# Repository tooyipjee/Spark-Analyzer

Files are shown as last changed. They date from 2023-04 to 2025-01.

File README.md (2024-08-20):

# Spark Analyzer: The Programmable USB-C Power Delivery Analyzer & Power Supply

<p align="center">
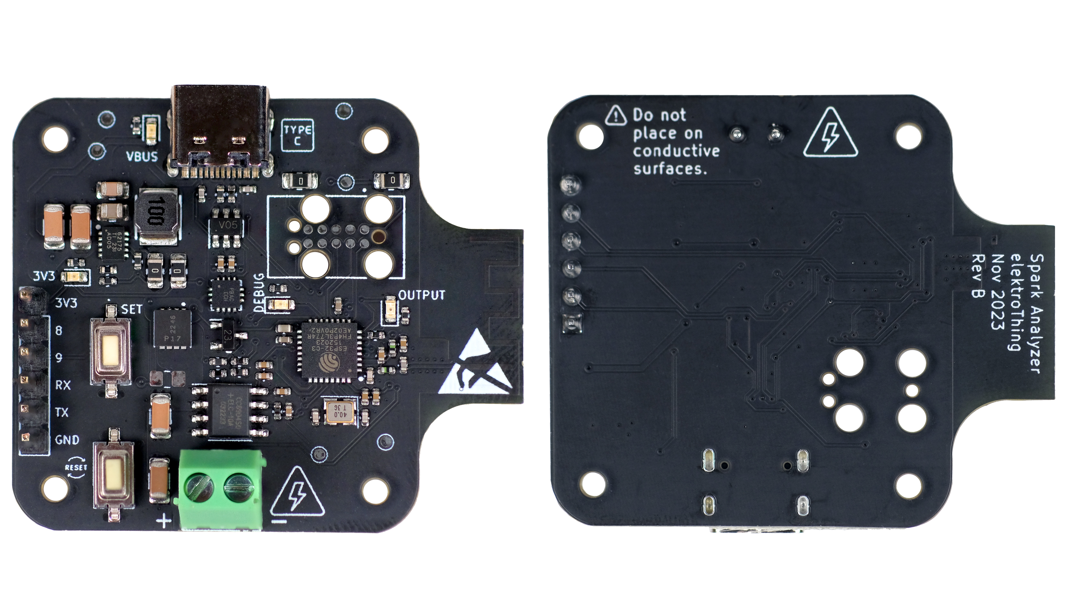
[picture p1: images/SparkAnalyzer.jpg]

</p>

**Just received your Spark Analyzer? Check out our [quickstart guide](https://www.elektrothing.com/spark-analyzer-quickstart)!**

The **Spark Analyzer** excels in power management. It is a versatile ESP32-powered device tailored for enhancing project development and debugging processes. It is fully compatible with USB-C Power Delivery (PD) and also supports the Programmable Power Supply (PPS) feature, allowing for precise control and management of power. Its compact design facilitates easy inline integration with existing setups, providing essential insights and control over power delivery.

Equipped with WiFi and BLE, the Spark Analyzer offers wireless connectivity, enabling developers to remotely monitor and adjust voltage levels, log data, and analyze power consumption through a user-friendly interface. This design prioritizes convenience and efficiency, removing the need for physical buttons and supporting distance operation.

Fully funded on Crowdsupply [now](https://www.crowdsupply.com/elektrothing/spark-analyzer).

Spark Analyzer (https://www.youtube.com/watch?v=IWUR4Ur0Dy4)

## Features:

1. **Configure USB Power Delivery PD**: When the Spark Analyzer is connected to a USB port that supports Power Delivery (PD), you can configure the output voltage as 5V, 9V, 15V or 20V.

2. **Configure USB Programmable Power Supply PPS**: When the Spark Analyzer is connected to a USB port that supports Programmable Power Supply (PPS), then you can configure the output voltage between 3.3V and 21V in steps of 20 mV. You can also limit the current up to 3A in steps of 50mA.

3. **Power Analysis**: The Spark Analyzer comes with a current sensor. This allows for accurate current draw measurements, essential for understanding power usage in your projects.

4. **Wireless Control**: Untehther your development process with the Spark Analyzer’s wireless capabilities. With both WiFi and BLE, this tool allows remote control and data logging. Users can adjust settings and monitor data from a distance, offering a more flexible development experience.

5. **Open Source & Programmable**: As an open-source device, the Spark Analyzer offers unmatched versatility. It is fully programmable, allowing you to tailor its functionality to your specific applications. This customization extends to software and hardware, opening up endless possibilities for creative and efficient project development.

6. **Compact Design**: Designed for convenience, the Spark Analyzer's compact and sleek form factor allows for seamless integration into existing setups. Its compatibility with USB PD power sources and inline integration capability minimizes the need for additional equipment or extensive redesign, making it a versatile and user-friendly addition to any development environment.

5. **Safety**: Safety is crucial when working with electricity and is at the heart of Spark Analyzer. An integrated output FET allows for software programmable current limit that switches off the power in high-current scenarios.

## Specifications

#### Power
- **Negotiable Power Delivery**: Options of 5 VDC, 9 VDC, 12 VDC, 15 VDC, 20 VDC; max 5 A (100 W at 20 VDC). It is also PPS compatible up to 21 VDC. Note: the Spark Analyzer comes preinstalled with firmware that supports PD. If you want to use PPS you can load this version instead: [WebApp_PPS](https://github.com/tooyipjee/Spark-Analyzer/tree/master/PlatformIO/WebApp_PPS).
- **USB Type-C Port**: For power delivery and integrated JTAG programming.
- **ON Semiconductor [FUSB302MPX](https://www.onsemi.com/pdf/datasheet/fusb302b-d.pdf)**: Programmable USB Type-C control and USB PD communication.
- **ESD Protection**: On D+/D-/CC1/CC2 pins.
- **Texas Instruments [TPS62175DQCT](https://www.ti.com/product/TPS62175/part-details/TPS62175DQCT)**: 3.3 VDC 0.5 A max output DC-DC Step-Down Converter.
- **Power Output**: 3.5 mm, 2-position terminal block.

#### I/O Configuration
- **GPIOs**: 4 GPIOs (I2C, UART, SPI compatible).
- **Power Pins**: 1x 5 VDC and 1x GND.

#### Microcontroller
- **Model**: [ESP32-C3FH4](https://www.espressif.com/sites/default/files/documentation/esp32-c3_datasheet_en.pdf) with 40 MHz crystal.
- **Wi-Fi**: 802.11b/g/n.
- **Bluetooth**: BLE 4.2.
- **Flash Memory**: 4 MB.

#### Interface
- **3x LED Indicators**
  - Power On
  - Output Enable
  - Programmable LED/Debug
- **Buttons**
  - Reset
  - Programmable Button/Debug

#### Programming
- **Integrated JTAG Controller**: For programming.
- **USB-C**: Built-in USB JTAG programmer (ESP32-C3), compatible with Arduino. Select ESP32-C3 Dev Board.

#### Output
- **Current Output**: [CC6904SO-10A](https://datasheet.lcsc.com/lcsc/2304140030_Cross-chip-CC6904SO-10A_C469389.pdf).
- **Current Sensor**: Hall Effect Current Sensor.
- **Output Enable**: [DMP3017SFG-7 FET](https://www.diodes.com/assets/Datasheets/products_inactive_data/DMP3017SFG.pdf).

<p align="center">
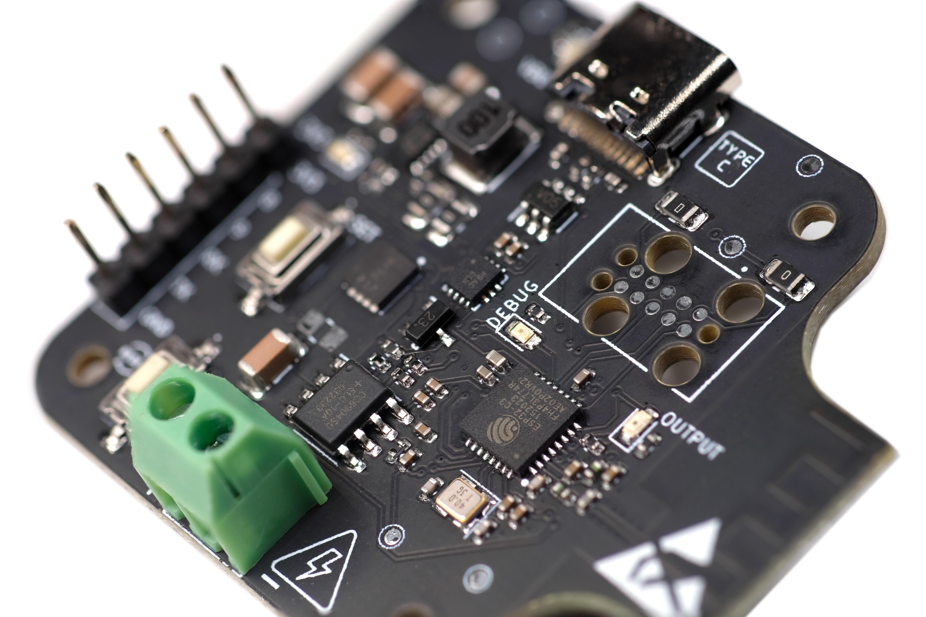
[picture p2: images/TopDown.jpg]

</p>

## Spark Analyzer Mobile App

<p align="center">
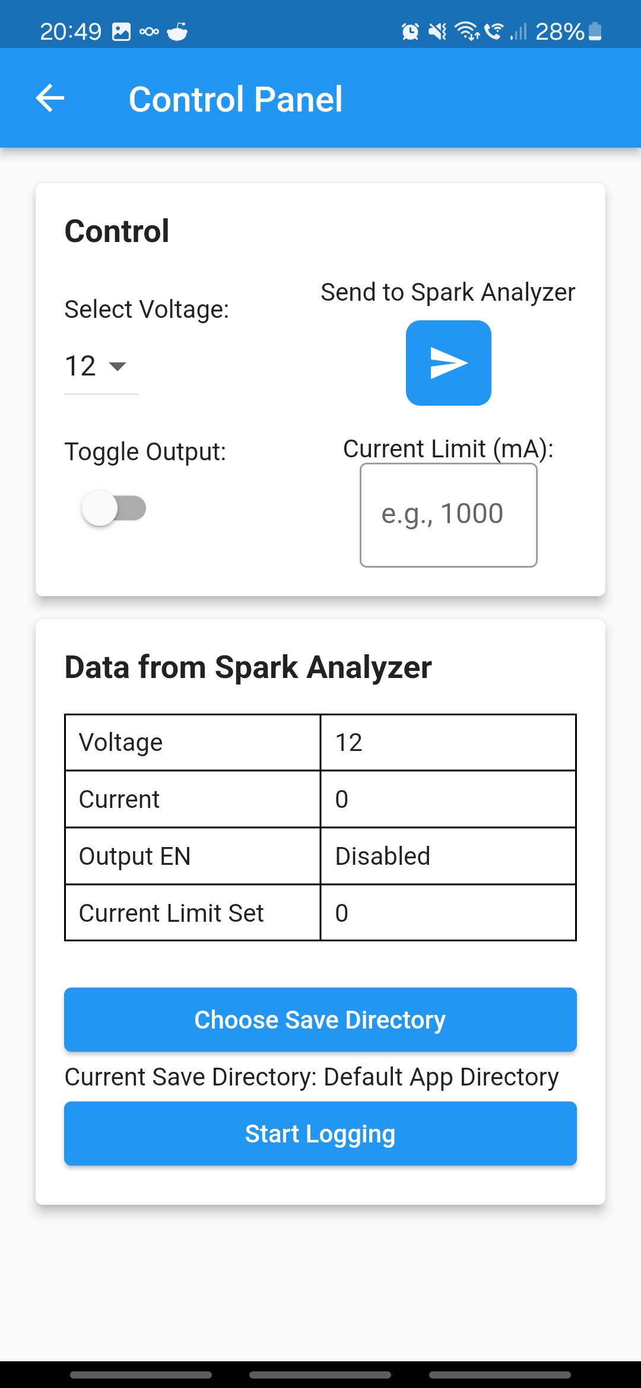
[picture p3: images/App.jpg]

</p>

> **Note**: The Spark Analyzer Mobile App is currently in active development. The features described below are subject to change as we continue to improve the app.

The Spark Analyzer Mobile App, currently done for [Android](https://play.google.com/store/apps/details?id=com.elektrothing.SparkAnalyzer&hl=en&gl=US) (iOS support is available via [RemoteXY](https://apps.apple.com/us/app/remotexy/id1168130280), is the perfect companion to your Spark Analyzer device. It simplifies monitoring and controlling power delivery with these key features:

- **Voltage Selector**: Easily choose from different voltage levels (5 VDC, 9 VDC, 15 VDC, or 20 VDC) using a user-friendly selector.
- **Output Toggle**: Turn the power output on or off conveniently with a toggle switch.
- **Current Logging**: Save current draw as a .csv file.
- **Current Limit**: Ability to set a software current trip as a safety feature.
- **Read-time Display**: View current set point, current draw and output enable in real time on your phone.

### Key Features:

- **Voltage Selector**: The app comes with a user-friendly voltage selector that allows you to easily choose from the different voltage levels supported by the UCPD protocol. Whether you need 5V, 9V, 15V, or 20V, switching between these options is just a tap away.

- **Output Toggle**: Need to turn the power output on or off? The app features a convenient toggle switch that gives you full control over the Spark Analyzer's output, making it simple to manage your device remotely.

- **Current Draw Chart**: Keep an eye on your project's power consumption with the app's real-time current draw chart. This feature provides a graphical representation of the current being drawn, helping you to monitor and optimize your power usage effectively.

### Future Developments:

The Spark Analyzer Mobile App is continuously being improved, with several new features in the pipeline. Upcoming updates will include the ability to export logs for further analysis, set current limits to prevent overcurrent scenarios, and much more.

## Testing for Performance

At the heart of Spark Analyzer's design is a commitment to reliability and performance. To ensure that Spark Analyzer stands up to real-world demands, we subjected it to testing under use conditions.

### Max Current Test: 3A at 9V
Under a load condition of 3A at 9V, Spark Analyzer showcased its robust power delivery capabilities without any hitches.

<p align="center">
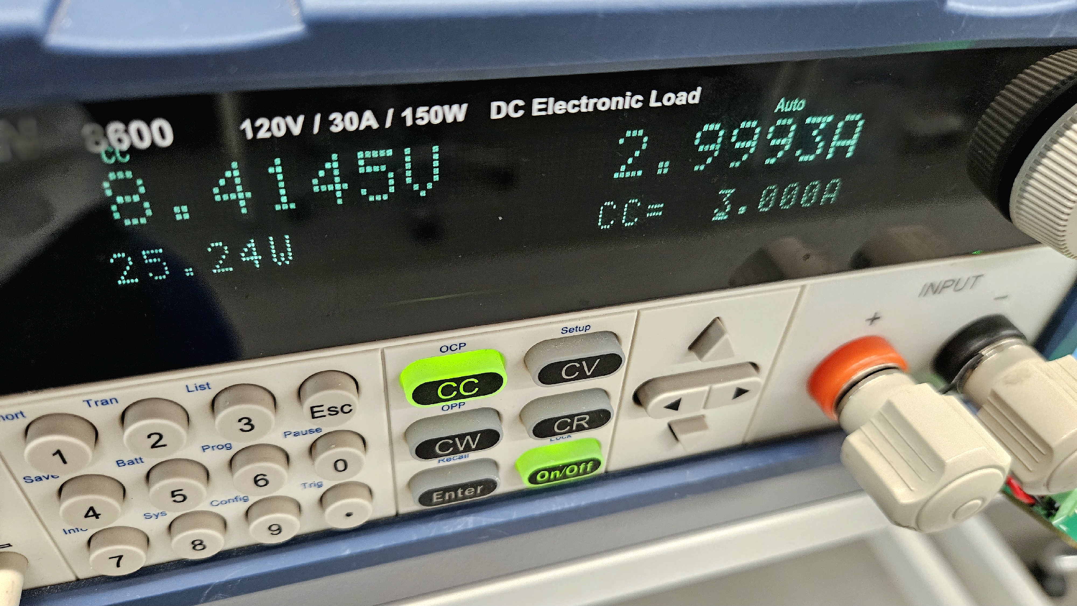
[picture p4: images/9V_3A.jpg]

</p>

### Max Voltage Test: 1.5A at 20V
Even at its maximum voltage output of 20V with a 1.5A load, Spark Analyzer continued to perform seamlessly, demonstrating its versatility and reliability.

<p align="center">
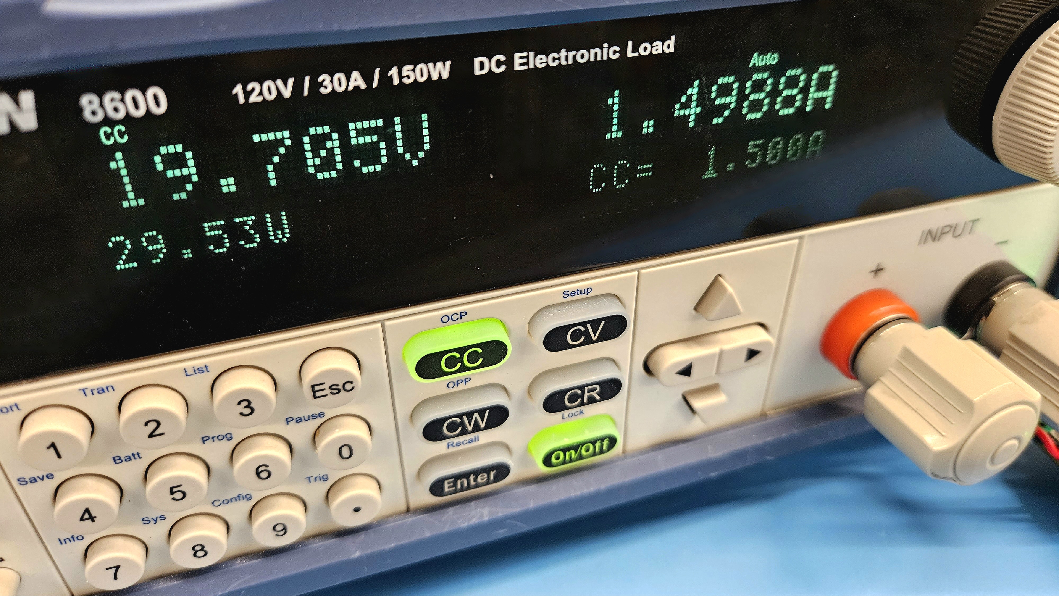
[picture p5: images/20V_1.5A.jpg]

</p>

### Thermal Performance
Safety and efficiency are paramount. We took a thermal image of the board under these testing conditions to ensure that all components remained within safe temperature limits. The results were impressive: the entire board stayed cool, with the warmest component being the ESP32 microcontroller, which only reached around 40°C.

<p align="center">
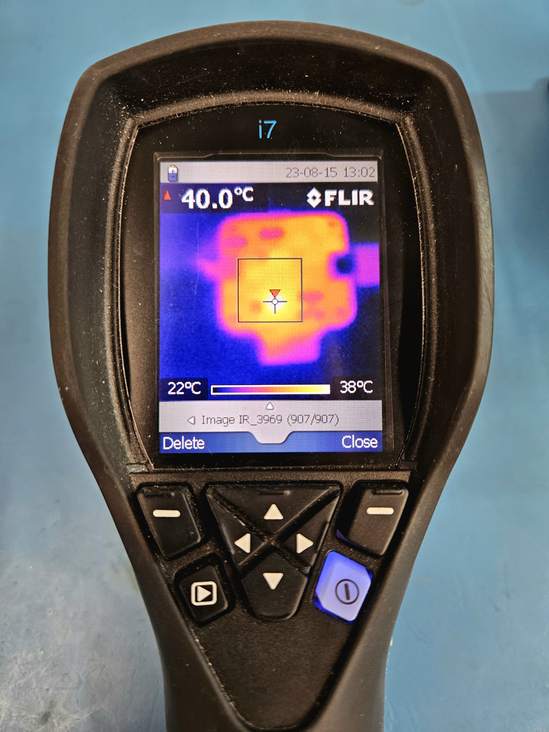
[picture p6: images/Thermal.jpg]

</p>

These tests underscore Spark Analyzer's commitment to delivering a product that is not only feature-rich but also reliable, safe, and efficient. With Spark Analyzer, you're investing in a device that's been tried and tested to ensure optimal performance under all conditions.

## Package Contents:

- 1x Spark Analyzer
- Additional components (Specify as per your package)

## Manufacturing & Logistics:

Our designs have undergone rigorous testing and verification. We've already produced a pilot batch, and our manufacturing partners are geared up for full-scale production. All Spark Analyzer units will be shipped globally, ensuring timely delivery to our backers.

## Comparison: Spark Analyzer vs PD Micro vs Lab Power Supply

| | Spark Analyzer | [PD Micro](https://www.mouser.co.uk/ProductDetail/Crowd-Supply/CS-PDMICRO-01?qs=TuK3vfAjtkXixx0TeJooNQ%3D%3D) | [TinyPICO V3](https://www.conrad.com/en/p/joy-it-com-zy12pdn-converter-1-pc-s-2475888.html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) | [Joy-IT COM ZY12PDN](https://shop.pimoroni.com/products/tinypico-v2?variant=39285089534035) |
|---|---|---|---|---|
| **Microcontroller** | ESP32-C3 | ATmega32U4 | ESP32-PICO-D4 | Not Applicable |
| **WiFi Connectivity** | Available (802.11b/g/n) | Not Available | Available | Not Available |
| **Bluetooth Connectivity** | Available (BLE 4.2) | Not Available | Available | Not Available |
| **Flash Memory** | 4 MB | Not Specified | 4 MB | Not Specified |
| **USB-C Power Delivery** | Supported | Supported | Not Supported | Supported |
| **Output Control** | Adjustable | Adjustable | Not Specified | Adjustable |
| **Wireless Control** | Yes | No | Yes | No |
| **Smartphone App Support** | Yes | No | No | No |
| **Power Analysis** | Accurate | Basic | Not Specified | Basic |
| **Design** | Compact and Sleek | Compact | Ultra-Small | Compact |
| **Open Source Status** | Yes | Yes | Yes | No |
| **Programming Interface** | USB + JTAG | USB | USB | Not Applicable |
| **Inline Integration** | Yes | No | Not Applicable | No |
| Power Delivery Range | 5-20 VDC Supported | 5-20 VDC Supported | Not Supported | 5-20 VDC Supported |
| **Price (USD)** | $49 | $28 | $22 | $16 |

## License

MIT License

Copyright (c) 2023 elektroThing

Permission is hereby granted, free of charge, to any person obtaining a copy
of this software and associated documentation files (the "Software"), to deal
in the Software without restriction, including without limitation the rights
to use, copy, modify, merge, publish, distribute, sublicense, and/or sell
copies of the Software, and to permit persons to whom the Software is
furnished to do so, subject to the following conditions:

The above copyright notice and this permission notice shall be included in all
copies or substantial portions of the Software.

THE SOFTWARE IS PROVIDED "AS IS", WITHOUT WARRANTY OF ANY KIND, EXPRESS OR
IMPLIED, INCLUDING BUT NOT LIMITED TO THE WARRANTIES OF MERCHANTABILITY,
FITNESS FOR A PARTICULAR PURPOSE AND NONINFRINGEMENT. IN NO EVENT SHALL THE
AUTHORS OR COPYRIGHT HOLDERS BE LIABLE FOR ANY CLAIM, DAMAGES OR OTHER
LIABILITY, WHETHER IN AN ACTION OF CONTRACT, TORT OR OTHERWISE, ARISING FROM,
OUT OF OR IN CONNECTION WITH THE SOFTWARE OR THE USE OR OTHER DEALINGS IN THE
SOFTWARE.

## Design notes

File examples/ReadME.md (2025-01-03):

# Spark Analyzer Quickstart Guide

Thank you for your purchase! Let's get started.

Your Spark Analyzer ships with the Web App PD firmware. Follow this guide to begin. For more detailed information, refer to the datasheet in the [project repository](link-to-repository).

## Hardware Setup

1. **Connect to a USB-C PD Compatible Wall Wart:** Ensure your wall adapter supports USB-C PD by looking for "USB PD" markings or output specifications above 5V (e.g., 9V, 15V, 20V).  USB-C alone doesn't guarantee PD compatibility. [See an example](link-to-example-image).

2. **Power On:** Turn on your Spark Analyzer. A blinking debug LED (5 times) confirms the firmware is loaded correctly.

## WiFi Connection

1. **Connect to "Spark Analyzer" WiFi:**  Using a WiFi-enabled device (phone or laptop), connect to the "Spark Analyzer" network.  Internet access isn't required for this step.

2. **Configure WiFi:** Open a web browser and navigate to `192.168.4.1` to access WiFiManager. Enter your home or office WiFi credentials.

## Accessing the Web App

### Find Device IP

* **Serial Monitor:** Connect the device to your computer via USB. The IP address will display in your IDE's serial monitor once connected to WiFi.

* **BLE Advertisement:**  Use a BLE scanner app (like NRF Connect) to locate the device broadcasting its IP address.

### Web App Interface

1. **Launch Web App:** Enter the device's IP address into your web browser.

### Web Interface Overview

* **Current Graph:**  Displays real-time current measurements.
* **Select and Set Voltage:** Choose and apply the desired voltage.
* **Output Control:**  Turn the device's power output on or off.

That's it! You're ready to control your Spark Analyzer's USB-C PD functions. For more examples and applications, explore the [project repository](link-to-repository).

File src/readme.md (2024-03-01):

# Spark Analyzer Firmware Collection

Welcome to the Spark Analyzer Firmware Collection! This repository is a comprehensive suite of firmware scripts specifically designed for the Spark Analyzer, a versatile tool for power management and smart device control. The firmware collection showcases a range of functionalities, from wireless communication and smart home integration to precise power delivery and current monitoring. Each script is crafted to demonstrate and utilize the unique features of the Spark Analyzer, making them ideal for a variety of applications in IoT, smart home, and power management sectors. Below is an overview of the available firmware scripts:

Most of them are Arduino examples and there is one template PlatformIO firmware that you can use to build your projects. Here are the main scripts/examples;
## 1. [Spark Analyzer Firmware with BLE and USB-C PD Control](https://github.com/tooyipjee/Spark-Analyzer/tree/master/src/Arduino/flutter_controller)
- **Purpose**: Focuses on Bluetooth Low Energy (BLE) communication for remote control and monitoring. [Google Play](https://play.google.com/store/apps/details?id=com.elektrothing.SparkAnalyzer&hl=en&gl=US)
- **Key Features**:
  - Manages USB-C Power Delivery (PD) for voltage control.
  - Implements a moving average filter for stable current readings.
  - Utilizes EEPROM for storing voltage settings.
  - LED indicators for operational status.

## 2. [Spark Analyzer Firmware for ESP-NOW Communication](https://github.com/tooyipjee/Spark-Analyzer/tree/master/src/Arduino/esp-now)
- **Purpose**: Provides host and peripheral setup for ESP-NOW communication.
- **Host Script**:
  - Sends voltage and enable/disable commands to peripherals.
- **Peripheral Script**:
  - Receives commands to control a NeoPixel LED strip and manage USB-C PD.
  - Processes structured data from the host.

## 3. [Spark Analyzer Firmware for Matter Integration](https://github.com/tooyipjee/Spark-Analyzer/tree/master/src/Arduino/matter_controller)
- **Purpose**: Integrates with Matter (formerly Project CHIP) for smart home connectivity.
- **Key Features**:
  - Control of an LED via Matter's OnOff cluster.
  - USB-C PD integration for voltage management.
  - Toggle button implementation with debouncing.
  - Serial communication for device status and debugging.

## 4. [Spark Analyzer Template Firmware for Custom Applications](https://github.com/tooyipjee/Spark-Analyzer/tree/master/src/Arduino/template)
- **Purpose**: Serves as a base for developers creating custom applications.
- **Key Features**:
  - Includes USB-C PD management for voltage setting.
  - Real-time ADC reading with a moving average filter.
  - Configurable initial output state and current limit.
  - Serial communication for debugging and status updates.

## 5. [PlatformIO Template Firmware for USB-C PD and Current Monitoring](https://github.com/tooyipjee/Spark-Analyzer/tree/master/src/PlatformIO/SparkAnalyzer)
- **Purpose**: Optimized for use in PlatformIO environment.
- **Key Features**:
  - USB-C PD initialization and management.
  - Real-time current measurement with a moving average filter.
  - Function prototypes for better code organization.
  - Configurable update interval for monitoring.

Each firmware script in this collection highlights different capabilities of the Spark Analyzer, catering to a wide range of applications in power management, smart home systems, and IoT devices.

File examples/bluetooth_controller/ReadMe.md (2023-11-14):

### Spark Analyzer Code Guide

#### Overview
The Spark Analyzer code is designed for a Bluetooth Low Energy (BLE) connected power supply controller. It allows remote monitoring and control of a power supply's voltage and current draw via the RemoteXY app. The code includes functionality for adjusting voltage, turning the power supply on and off, and monitoring current consumption.

#### How the Code Works

1. **Initialization**: Sets up BLE connectivity, preferences, and initializes the USB-C Power Delivery (PD) with pre-stored voltage settings.

2. **Remote Control Interface**: Implemented using the RemoteXY service, which provides a graphical user interface (GUI) on a smartphone for remote interaction.

3. **Voltage Control**: Allows the selection of output voltages (5V, 9V, 12V, 15V, 20V) via a selector on the RemoteXY app interface.

4. **On/Off Control**: Includes an on/off switch on the RemoteXY app to enable or disable the power output.

5. **Current Monitoring**: Measures and displays the current draw in milliamperes (mA) on the app.

6. **ADC Filtering**: Uses a moving average filter to smooth out the analog-to-digital converter (ADC) readings for accurate current measurements.

7. **Preferences Management**: Saves and retrieves user settings (like set voltage) using the ESP32's Preferences library.

#### How to Use with RemoteXY App

##### Installing RemoteXY App
1. **Android Devices**:
   - Open the Google Play Store.
   - Search for "RemoteXY: Arduino control".
   - Install the app.

2. **iOS Devices**:
   - Open the Apple App Store.
   - Search for "RemoteXY: Arduino control".
   - Download and install the app.

##### Connecting to Spark Analyzer
1. **Open the RemoteXY App** on your smartphone.

2. **Connect to the Device**:
   - In the app, select the connection mode (BLE).
   - Scan for available devices and select "Spark Analyzer".

3. **Interface Overview**:
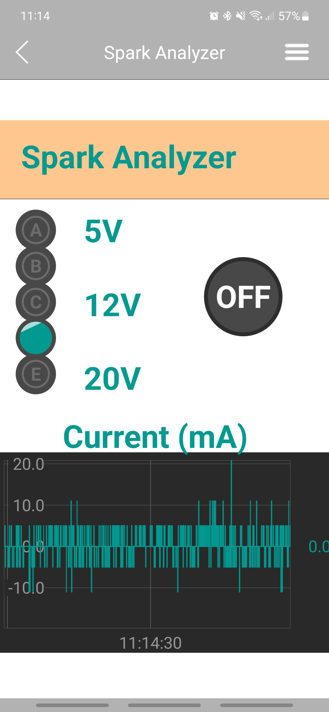
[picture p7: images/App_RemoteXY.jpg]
App Interface RemoteXY App Interface


   - **Voltage Selector (A to E)**: Select between 5V, 9V, 12V, 15V, and 20V. Labels indicate the corresponding voltages (5V, 12V, and 20V).
   - **On/Off Button**: A toggle switch to turn the power output on or off.
   - **Current Draw Chart**: Displays real-time current consumption in mA.

4. **Using the Interface**:
   - **Selecting Voltage**: Tap on the voltage selector (A to E) to choose the desired output voltage. Only select among the labeled voltages (5V, 12V, and 20V) for safety.
   - **Toggling Power**: Press the on/off button to enable or disable the power output.
   - **Monitoring Current**: View the current draw chart to see the live current consumption in milliamperes.

5. **Data Synchronization**: The app will continuously synchronize data with the Spark Analyzer, providing real-time updates on voltage and current readings.

#### Safety and Precautions
- Ensure that your power supply and hardware are compatible with the selected voltages and current levels.
- Use the app within the BLE range for stable communication.
- Regularly check connections and components for safety.

This guide assumes familiarity with basic electronic and BLE concepts. For specific hardware setup or advanced configurations, refer to the device's manual or technical documentation.

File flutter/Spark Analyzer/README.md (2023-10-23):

# ble_scan_demo

A new Flutter project.

## Getting Started

This project is a starting point for a Flutter application.

A few resources to get you started if this is your first Flutter project:

- [Lab: Write your first Flutter app](https://docs.flutter.dev/get-started/codelab)
- [Cookbook: Useful Flutter samples](https://docs.flutter.dev/cookbook)

For help getting started with Flutter development, view the
[online documentation](https://docs.flutter.dev/), which offers tutorials,
samples, guidance on mobile development, and a full API reference.

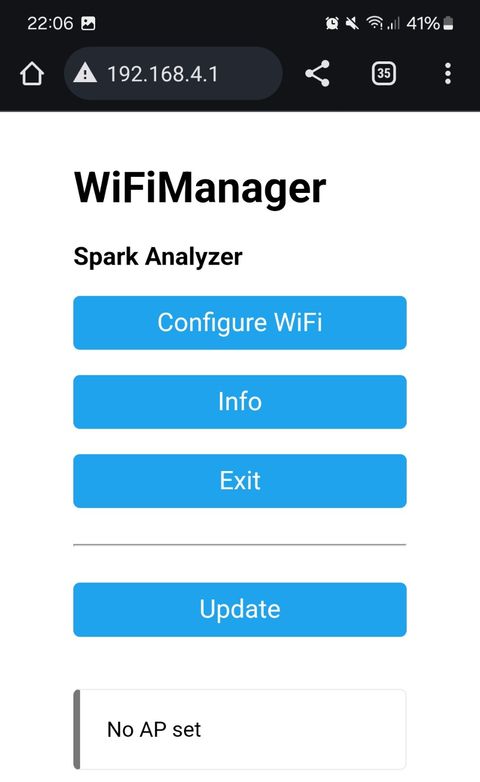
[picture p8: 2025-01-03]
images/quickstart/wifi_manager.jpeg

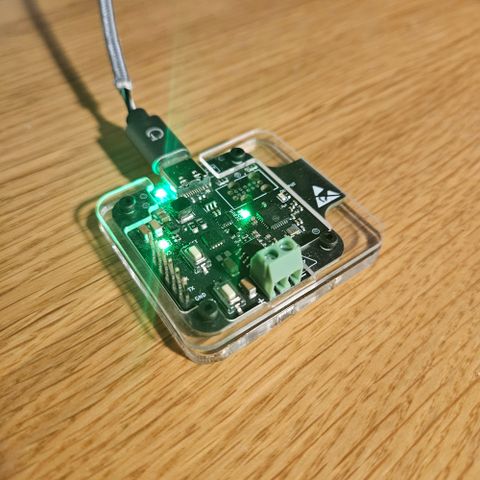
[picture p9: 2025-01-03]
images/quickstart/spark_analyzer_plugged.jpeg

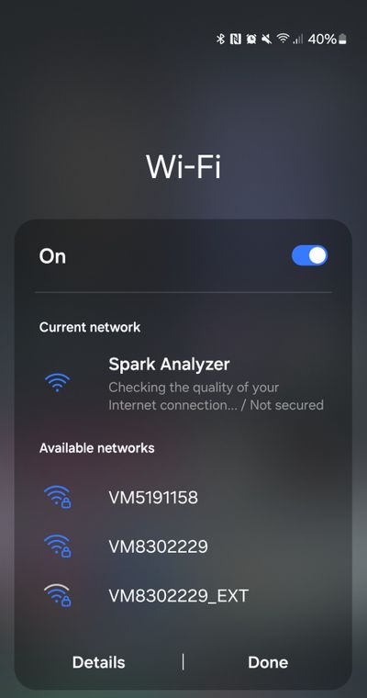
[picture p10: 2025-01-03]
images/quickstart/android_wifi.jpeg

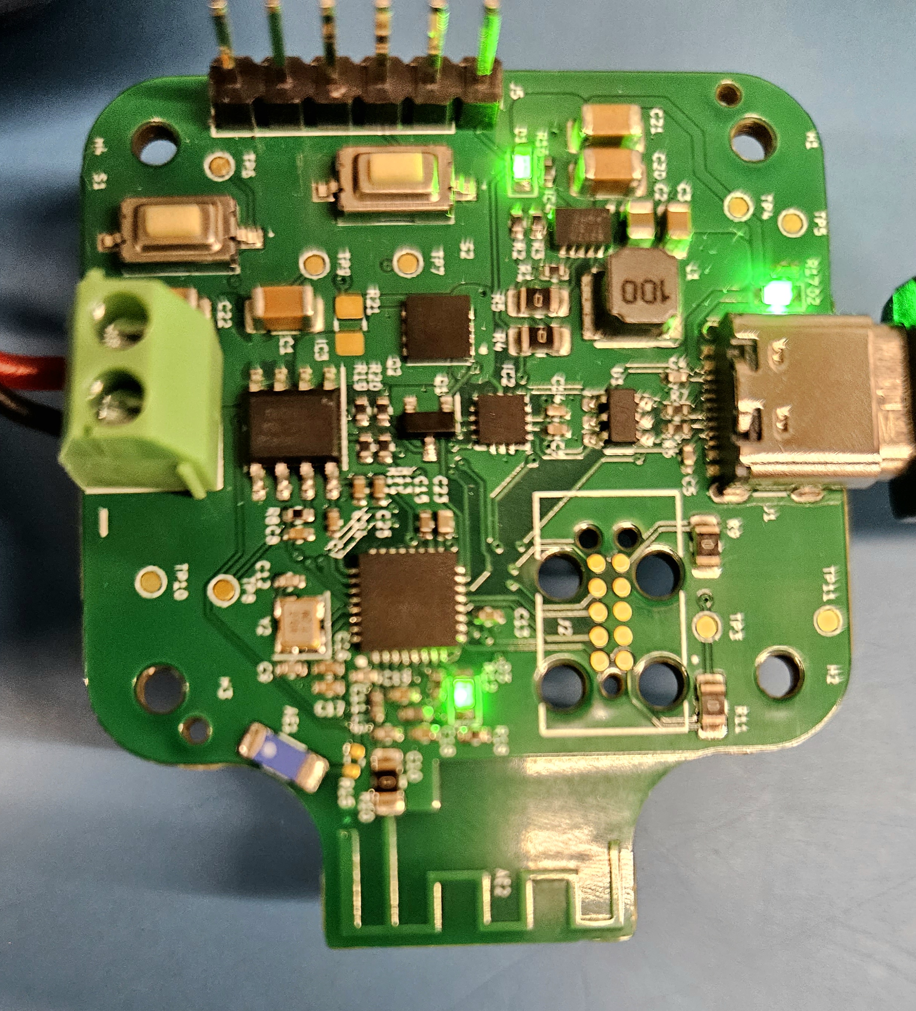
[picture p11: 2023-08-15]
images/ThermalColour.jpg

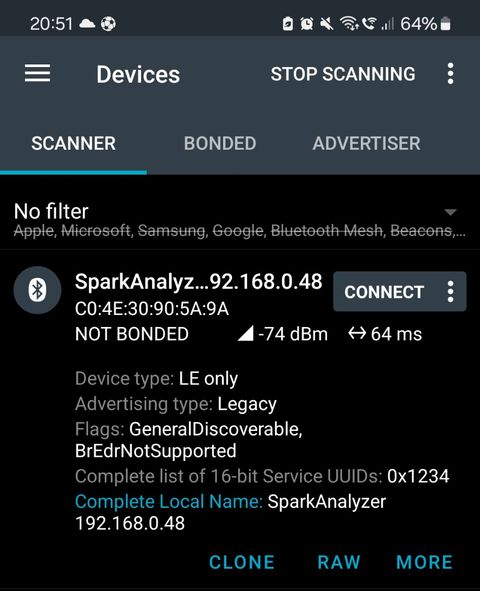
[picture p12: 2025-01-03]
images/quickstart/nrf_connect.jpeg

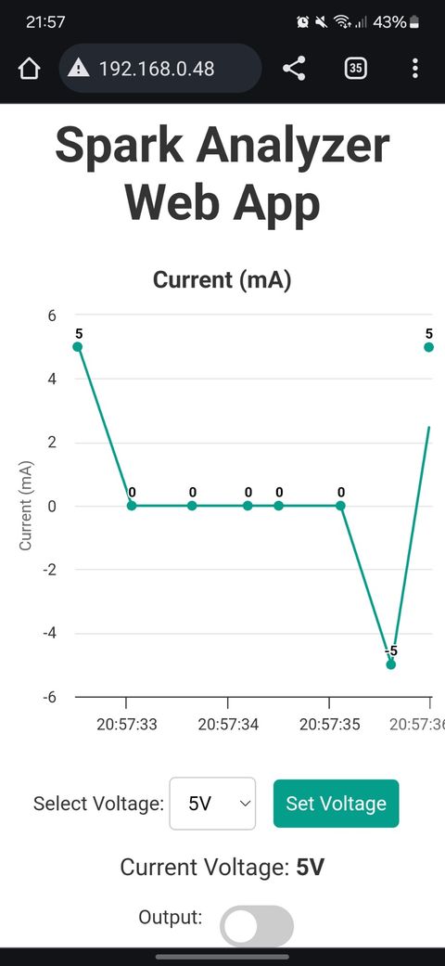
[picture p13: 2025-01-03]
images/quickstart/spark_analyzer_webapp.jpeg

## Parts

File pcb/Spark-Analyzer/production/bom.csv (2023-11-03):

Designator | Footprint | Quantity | Value | LCSC Part #
AE2 | Texas_SWRA117D_2.4GHz_Left | 1 | Antenna
C1, C20, C21, C22 | 1206 | 4 | 10u_1206 | C466808
C10 | 0402 | 1 | 4p | C311704
C11 | 0402 | 1 | 5p | C1573
C12, C9 | 0402 | 2 | 20p | C1554
C13, C15 | 0402 | 2 | 1u | C52923
C14, C16, C17, C18, C19, C24, C25, C6, C7, C8 | 0402 | 10 | 100n | C307331
C2 | 0805 | 1 | 22u | C602037
C23 | 0402 | 1 | 10u_0402 | C315248
C3 | 0805 | 1 | 10u | C15850
C4, C5 | 0402 | 2 | 100p | C1546
D1, D2, D4 | 0603 | 3 | Green_0603 | C72043
D3 | 0603 | 1 | Yellow_0603 | C72038
H1, H2, H3, H4 | MountingHole_2.2mm_M2 | 4 | MountingHole
IC2 | WQFN-14-1EP_2.5x2.5mm_P0.5mm_EP1.45x1.45mm | 1 | FUSB302MPX | C442699
IC3 | SOP-8_3.9x4.9mm_P1.27mm | 1 | CC6904SO-10A | C469389
IC4 | SON50P200X300X80-11N | 1 | TPS62175DQCT | C32097
IC5 | QFN50P500X500X90-33N-D | 1 | ESP32-C3FH4 | C2858491
J1 | GT-USB-7010A | 1 | GT-USB-7010 | C963370
J2 | TC2050-IDC | 1 | TC2050-IDC
J3 | KF350352P | 1 | KF350-3.5-2P | C474892
J5 | PinHeader_1x06_P2.54mm_Vertical | 1 | Conn_01x06 | C492405
L1 | INDPM4040X300N | 1 | 10uH | C38117
L2, L3 | 0402 | 2 | 1.8nH
Q1 | SOT95P237X125-3N | 1 | DTC143ECA-TP
Q2 | DMP3007SFG7 | 1 | DMP3017SFG-7 | DMP3017SFG
R1 | 0402 | 1 | 100k | C25741
R11, R4, R5, R9 | 0805 | 4 | 0 | C17477
R12, R13, R14, R19 | 0402 | 4 | 10k | C25744
R16, R17, R18, R22 | 0402 | 4 | 2.7k | C25885
R2 | 0402 | 1 | 1M2 | C413030
R20 | 0402 | 1 | 1k | C11702
R21 | 0805 | 1 | DNF_0805
R3 | 0402 | 1 | 383k | C163468
R6, R7 | 0402 | 2 | 22 | C25092
R8 | 0402 | 1 | 100 | C25076
S1, S2 | TS1101CW | 2 | TS-1101-C-W | C318938
TP10, TP11, TP3, TP4, TP5, TP8 | TestPoint_Pad_D1.0mm | 6 | TestPoint
U1 | SOT-23-6 | 1 | SRV05-4
Y2 | Crystal_SMD_2520-4Pin_2.5x2.0mm | 1 | SX25Y040000BF1T-C | C271649

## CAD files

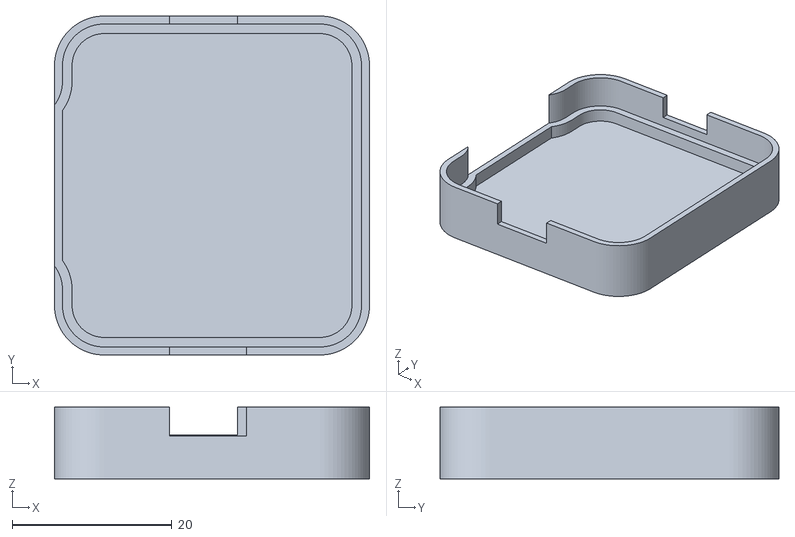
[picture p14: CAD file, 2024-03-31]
images/enclosure/Enclosure v3.stl
39.4 x 42.4 x 9.00

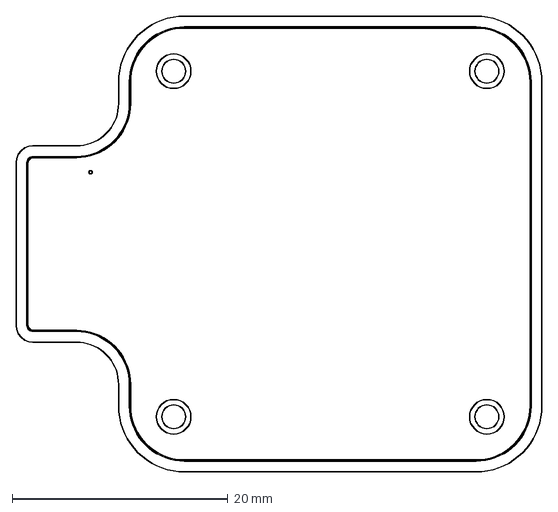
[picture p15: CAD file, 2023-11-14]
pcb/Spark-Analyzer/production/Board Outline with Margins.dxf
48.7 x 42.2 mm

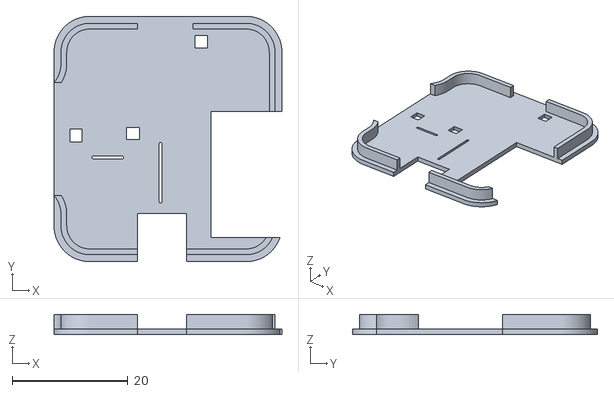
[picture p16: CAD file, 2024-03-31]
images/enclosure/Lid v1.stl
39.4 x 42.4 x 3.50

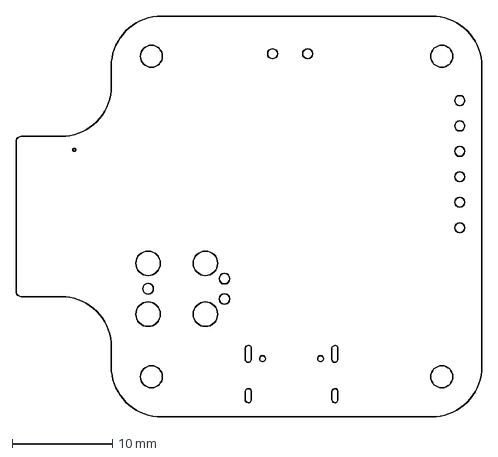
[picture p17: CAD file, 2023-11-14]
pcb/Spark-Analyzer/production/PCB_Outline.dxf
46.5 x 40.0 mm

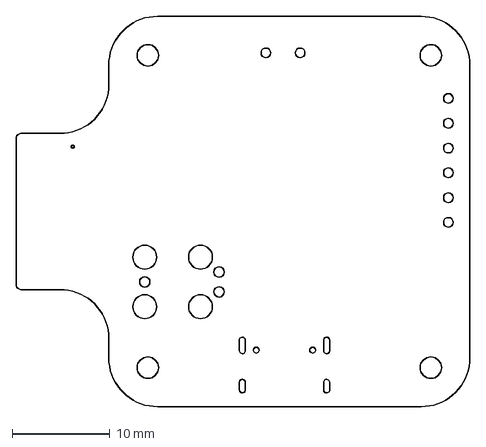
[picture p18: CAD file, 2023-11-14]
pcb/Spark-Analyzer/production/Board Outline.dxf
46.5 x 40.0 mm

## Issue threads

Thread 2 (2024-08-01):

How to configure 3.3V

doniks, 2024-08-01:
Just received my spark analyzer and plugged it in for the first time :heart:

I could
* connect to the spark analyzer access point
* configure my local wifi
* scan the ble advertisement to get the local IP
* open that IP in my browser
* turn it on
* measured it to be 5V
* also 9v works ok

so far so good, however,
* I don't see any way to configure voltages other than 5, 9, 12, 15, 20, like "Precisely control voltage from 3.3V to 21V at 20 mV resolution"
* I also don't see how to "set current limits up to 3A with 50mA resolution"

Is it somehow in ... I don't know "PD mode" and I have to switch it somehow to PPS?

tooyipjee, 2024-08-01:
The out of the box demo is a PD example.
PD doesn't support precise voltage control, you need to use PPS. You can
load this version instead;
Spark-Analyzer/PlatformIO/WebApp_PPS at master · tooyipjee/Spark-Analyzer
(github.com)
<https://github.com/tooyipjee/Spark-Analyzer/tree/master/PlatformIO/WebApp_PPS>

PPS supports 20mV and 50mA resolution, where it will trip the plug when you
draw too much.

Jason.

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

--
Sincerely,

*Jason Too*

doniks, 2024-08-01:
Thanks. Let me try that

doniks, 2024-08-01:
Mhm, so this was the first time using PlatformIO for me .. took me a while to figure out how to flash, but I can do it now, first with a blink example for `debug_led` and now I'm trying to flash back WebApp. It flashes and runs (according to some extra `Serial.println()` in `updateStatus()`, but I get

```
E (1442) SPIFFS: mount failed, -10025
[  1436][E][SPIFFS.cpp:89] begin(): Mounting SPIFFS failed! Error: -1
An Error has occurred while mounting SPIFFS
```

at boot, and no web interface.

could it be that maybe I wiped the SPIFFS with my blink example?! How could I make a kind of full flash, clean wipe ..

doniks, 2024-08-01:
ah, I had to [Use PlatformIO's "Upload Filesystem Image" command to upload the contents of the 'data' directory](https://github.com/tooyipjee/Spark-Analyzer/blob/master/PlatformIO/WebApp/src/main.cpp#L25)

doniks, 2024-08-01:
ok, so now I could reflash the WebApp version (including its filesystem) and that works again as expected.

I could also flash the WepApp_PPS version, including that corresponding FS. Now the website suggests that I can configure a granular voltage, and the serial terminal reflects that voltage, but if I measure the terminals with my voltmeter, I always see 5V

tooyipjee, 2024-08-01:
Please check that your USB-C plug supports PPS

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

doniks, 2024-08-01:
ahhhh :facepalm: I hadn't really grasped that before. So PPS is another feature/protocol that usb chargers might or might not support - got it.

Ok. seems my laptops usb-c ports do not support pps.

I have another charger which claims to support pps and lo and behold, I can configure it to 3.3 with that. Thanks! That clarifies my initial question. I could try and summarize it and make a PR to add it to the README!? Or other place if you prefer?

Having gotten that far now, I'd have a couple further feedback/remark
* It would be better if it would not fallback to 5v output if PPS is not supported. Rather keep the output off
* Maybe also show an error message in the web interface and maybe indicate via the led
* it seems that the web interface always comes up showing the output as on, even though it is (as expected) initially off
* even when I was unable to actually configure 3.3, because my charger was not PPS compatible the web app showed 3.3 . would it be possible to show 5 instead, or whatever would actually be put out
* it seems the PPS app does not remember the configured values. would it be sufficient to use the `Preferences` similar as in the WebApp? If so, I think I could make a PR for this
* oh, and just to not forget to state the obvious ... if at all possible, it would of course be much nicer if both PD and PPS could be supported in one firmware

tooyipjee, 2024-08-01:
Appreciate and feel free to make a PR yes! Haha thanks.

I need help from ppl like you!

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

doniks, 2024-08-03:
https://github.com/tooyipjee/Spark-Analyzer/pull/3

Closed 2024-08-04.

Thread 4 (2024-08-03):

WebApp_PPS should not deliver 5v if the power supply is not PPS capable

doniks, 2024-08-03:
previously discussed here: https://github.com/tooyipjee/Spark-Analyzer/issues/2

it seems that the WebApp_PPS falls back to delivering 5V if the power supply is not PPS capable. This could lead to people supplying higher voltage than what they want/anticipate.

I think the ideal solution would be to:
* detect that PPS is not supported
* show this in the web app
* turn off power output
* maybe the led can indicate some error state (does it support different colors? or rapid blinking)

tooyipjee, 2024-08-04:
Thanks for the feedback, I will try to get on this after the summer.

doniks, 2024-08-15:
when looking at the return value of `set_PPS()` :

```
bool retval = PD_UFP.set_PPS(PPS_V(ppsOutputVoltageV), PPS_A(ppsOutputCurrentLimitA));
      UART.printf("set_PPS(): %u\n", retval);
```
https://github.com/tooyipjee/Spark-Analyzer/pull/10/files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

I see a return value of
* `true` when I use a PPS capable adapter and then my voltmeter also shows the correct voltage configured
* `false` when I use a non-PPS adapter. And afterwards it delivers 5v.

So far that seems somewhat straight forward to detect success of failure. However, when I look at the actual library code, I find

> Set PPS Voltage in 20mV units, Current in 50mA units. return true if re-send request is needed
>   strict=true, If PPS setting is not qualified, return false, nothing is changed.
>   strict=false, if PPS setting is not qualified, fall back to regular power option

https://github.com/tooyipjee/Spark-Analyzer/blob/master/PlatformIO/WebApp_PPS/src/PD_UFP_Protocol.h#L145

which sounds less straight forward. in fact. I don't understand it

doniks, 2024-08-17:
added some more debugging here: https://github.com/tooyipjee/Spark-Analyzer/pull/11 `USE_PD_UFP_LOGGING`

which allows logging of detected power supply capabilities. I'm looking what I get from the various adapters I have lying around, but it's still confusing to me :( tbc

doniks, 2024-08-17:
maybe also better to [Examine the negotiated power value](https://github.com/ryan-ma/PD_Micro?tab=readme-ov-file#examine-the-negotiated-power-value) as per (upstream?) documentation and/or [Wait for USB PD PPS trigger completed](https://github.com/ryan-ma/PD_Micro?tab=readme-ov-file#wait-for-usb-pd-pps-trigger-completed)

doniks, 2024-08-18:
let me collect some logs and observations with the various chargers I have lying around

doniks, 2024-08-18:
# USB A
simplest case I guess, connecting to usb-A directly (specifically via a four port usb hub to the left port of my laptop)

1232: FUSB302 ver ID:A_revB
1273: 5.00V 1.00A supply ready
1273: USB attached CC2 vRd-USB

when pressing the reset button, it starts and then immediately restarts ...

ESP-ROM:esp32c3-api1-20210207
Build:Feb  7 2021
rst:0x1 (POWERON),boot:0x8 (SPI_FAST_FLASH_BOOT)
SPIWP:0xee
mode:DIO, clock div:1
load:0x3fcd5810,len:0x438
load:0x403cc710,len:0x90c
load:0x403ce710,len:0x2624
entry 0x403cc710
Initializing secondary serial port (GPIO pins)
Debug messages from Spark Analyzer code will be printed on this serial port
preferences.getType(V): 9
preferences.getType(A): 9
Mode: PPS
Voltage: 4.000 V
Current limit: 1.100 A
Connecting to wifi TP ..
Connected to wfif: TP (-72)
To access the web app, open your browser and navigate to -> http://192.168.1.244
[      1244] PPS mode, Voltage: 4.000 V, Current: 0 mA (1.100 A), Output: disabled
[      1276] PPS mode, Voltage: 4.000 V, Current: 0 mA (1.100 A), Output: disabled
Setup complete

1240: FUSB302 ver ID:A_revB
1282: 5.00V 1.00A supply ready
1282: USB attached CC2 vRd-USB
ESP-ROM:esp32c3-api1-20210207
Build:Feb  7 2021
rst:0x15 (USB_UART_CHIP_RESET),boot:0x8 (SPI_FAST_FLASH_BOOT)
Saved PC:0x42021efe
SPIWP:0xee
mode:DIO, clock div:1
load:0x3fcd5810,len:0x438
load:0x403cc710,len:0x90c
load:0x403ce710,len:0x2624
entry 0x403cc710
Initializing secondary serial port (GPIO pins)
Debug messages from Spark Analyzer code will be printed on this serial port
preferences.getType(V): 9
preferences.getType(A): 9
Mode: PPS
Voltage: 4.000 V
Current limit: 1.100 A
Connecting to wifi TP ..
Connected to wfif: TP (-72)
To access the web app, open your browser and navigate to -> http://192.168.1.244
[      1239] PPS mode, Voltage: 4.000 V, Current: 11 mA (1.100 A), Output: disabled
[      1271] PPS mode, Voltage: 4.000 V, Current: 11 mA (1.100 A), Output: disabled
Setup complete

1235: FUSB302 ver ID:A_revB
1277: 5.00V 1.00A supply ready
1277: USB attached CC2 vRd-USB
[     10000] PPS mode, Voltage: 4.000 V, Current: -5 mA (1.100 A), Output: disabled
[     20000] PPS mode, Voltage: 4.000 V, Current: 0 mA (1.100 A), Output: disabled

doniks, 2024-08-18:
# Ugreen adapter

this one seems to have some PPS capabilities. The charger has three usb c ports and one usb a port. the label is a bit scratched but as far as I can tell the different ports have different caps:

Power Delivery Fast Charger
Model: CD224

- USB-C1/C2 Output:
  - 5.0V@3.0A
  - 9.0V@3.0A
  - 12.0V@3.0A
  - 15.0V@3.0A
  - 20.0V@3.25A
  - 65W Max
- USB-C3 Output:
  - 5.0V@3.0A
  - 9.0V@3.0A ?? 2.0A ??
  - 12.0V@1.5A
  - 15??? W Max
- USB-A Output:
  - 4.5V@5.0A???
  - 5.0V@4.6A???
  - 5.0V@3.0A
  - ??V@2.0A
  - 12.0V@1.5??A
  - 22.5W Max

I think it's this one: https://nl.ugreen.com/collections/gan-oplader/products/ugreen-65w-usb-c-charger-4-poorts-oplader-pd-lader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 Can only find this in Dutch and it doesn't give specific details on the capabilities, but it has some complicated overview saying what is possible when connecting one/two/three/four devices in various combinations.

when I plug it in, I see log output from PD_UFP suggesting 5,9,12,15V PD capabilities (and 20V on USB-C1) and some PPS capabilities. Capabilities differ for C1/C2 versus C3. Then there's some logging about "2-stage startup", then the requested "PPS 3.30V 0.50A supply ready". this logging repeats every 5s until after ca 60s uptime, it resets and now only reports the four PD caps. afterwards it keeps running for the the next half hour (2770.026s) until I unplugged it. That behaviour seems reproducible. So, I guess something is not going well with the PPS negotiation

## USB-C3 Output

Mode: PPS
Voltage: 3.300 V
Current limit: 0.500 A
...
2241: FUSB302 ver ID:A_revB
2287: USB attached CC2 vRd-3.0
2288: TX Get_Src_Cap
2290: RX GoodCRC
2291: RX Soft_Rst
2293: TX Accept
2295: RX GoodCRC
2297: RX Src_Cap
2297:    [0] 5.00V 3.00A
2297:    [1] 9.00V 2.67A
2297:    [2] 12.00V 2.00A
2297:    [3] 15.00V 1.60A
2297:    [4] 3.30V-5.90V 3.00A PPS *
2297:    [5] 3.30V-11.00V 2.00A PPS
2299: TX Request
2301: RX GoodCRC
2305: RX Accept
2326: RX PS_RDY
2326: PPS 2-stage startup
2326: TX Request
2329: RX GoodCRC
2333: RX Accept
2354: RX PS_RDY
2354: PPS 3.30V 0.50A supply ready
7355: TX Request
7357: RX GoodCRC
7361: RX Accept
7382: RX PS_RDY
7382: PPS 3.30V 0.50A supply ready
[     10000] PPS mode, Voltage: 3.300 V, Current: -5 mA (0.500 A), Output: disabled
12383:TX Request
12385:RX GoodCRC
12389:RX Accept
12410:RX PS_RDY
12410:PPS 3.30V 0.50A supply ready
17411:TX Request
17413:RX GoodCRC
17418:RX Accept
17438:RX PS_RDY
17438:PPS 3.30V 0.50A supply ready
...
62667:RX GoodCRC
62672:RX Accept
62692:RX PS_RDY
62692:PPS 3.30V 0.50A supply ready
[     70000] PPS mode, Voltage: 3.300 V, Current: -5 mA (0.500 A), Output: disabled
ESP-ROM:esp32c3-api1-20210207
Build:Feb  7 2021
rst:0x1 (POWERON),boot:0x8 (SPI_FAST_FLASH_BOOT)
SPIWP:0xee
mode:DIO, clock div:1
load:0x3fcd5810,len:0x438
load:0x403cc710,len:0x90c
load:0x403ce710,len:0x2624
entry 0x403cc710
Initializing secondary serial port (GPIO pins)
Debug messages from Spark Analyzer code will be printed on this serial port
preferences.getType(V): 9
preferences.getType(A): 9
Mode: PPS
Voltage: 3.300 V
Current limit: 0.500 A
Connecting to wifi TP ..
Connected to wfif: TP (-77)
To access the web app, open your browser and navigate to -> http://192.168.1.244
[      1245] PPS mode, Voltage: 3.300 V, Current: 0 mA (0.500 A), Output: disabled
[      1277] PPS mode, Voltage: 3.300 V, Current: 0 mA (0.500 A), Output: disabled
Setup complete

1241: FUSB302 ver ID:A_revB
1283: USB attached CC2 vRd-3.0
1283: TX Get_Src_Cap
1286: RX GoodCRC
1287: RX Soft_Rst
1288: TX Accept
1290: RX GoodCRC
1292: RX Src_Cap
1292:    [0] 5.00V 3.00A *
1292:    [1] 9.00V 2.67A
1292:    [2] 12.00V 2.00A
1292:    [3] 15.00V 1.60A
1294: TX Request
1296: RX GoodCRC
1300: RX Accept
1432: RX PS_RDY
1432: 5.00V 3.00A supply ready
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
doniks, 2024-08-18:
# Philips DLP262IT
* USB-C:
  * 5V@3A
  * 9V@2A
  * 12V@1.5A
  * max 18W
* USB-A:
  * 5v@2.4A
  * max 12 W

1241: FUSB302 ver ID:A_revB
1282: USB attached CC2 vRd-3.0
1282: TX Get_Src_Cap
1285: RX GoodCRC
1286: RX Src_Cap
1286:    [0] 5.00V 3.00A *
1286:    [1] 9.00V 2.00A
1286:    [2] 12.00V 1.50A
1289: TX Request
1291: RX GoodCRC
1292: RX Accept
1518: RX PS_RDY
1518: 5.00V 3.00A supply ready

tooyipjee, 2024-08-20:
Thank for all your help @doniks.

I have been travelling and am now back and ready to address all these issues!

I have been developing spark analyzer with this actually - https://www.anker.com/uk/products/a2147

And all of the settings work, PD & PPS.

doniks, 2024-08-21:
Welcome home 😉.

Mhm. Yeah. Not totally sure how to proceed. I think this is the only PPS capable charger I have and the Spark Analyzer is the only PPS requesting device I have. So, it's difficult to narrow down which of the two is the problem.

I guess I have to buy some other gear... Do you have any experience with the PD Micro? As far as I understood that's where the FUSB driver code and the PD UFP Code comes from, yes? And I guess the chip that does the power negotiation is the same and PD Micro would have similar features to the Spark Analyzer?! But their github repo was last touched 3 years ago and last I checked I couldn't really find a place to order it...

Oh, and if I may- another question how does it work to supply the power to the Spark Analyzer electronics itself? I mean, we're negotiating the power we want to get from the charger and put out on the output terminals, but the SA itself needs power how is that arranged? I guess the output power and the SA internals supply come out of the same single supply. Even while we're re-negotiating it. .... I'm confused 😝

tooyipjee, 2024-08-21:
The Spark Analyzer has a wide range 3.3V input Switch Mode Power Supply. So
regardless of what the input voltage is, it will get stepped down to 3.3V
for the ESP32.

You're right about the PD Micro!

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

--
Sincerely,

*Jason Too*

rejnok93, 2024-09-14:
Hello, my 1st test of PPS firmware (WebApp_PPS) with Vention 30W GaN USB-C PPS (model FAKY0-EU) 1-port, its possible to set anything from 3.3V (measured OK) to 16.0V (if set more, voltmeter shows still 16V, if set lower than 3.3V voltmeter shows still 3.3V). But it seems that Spark Analyzer is not stable with 3.3V PPS, if connected anything to output terminal, Spark Analyzer resets to strange state (only VBUS LED lights, but 3V3 LED not!) or rarely resets to normal state (5V, output disabled)... Maybe some small dropouts in voltage during connecting of the load can lower 3V3 supply under ESP32 brownout voltage, maybe with some HW upgrade Spark Analyzer will be capable to output 3.3V and not only set with zero load.

tooyipjee, 2024-09-14:
Hi thanks for this, I'll test it with my wall adapter but thay explanation
is certainly plausible.

The SMPS on the 3V3 pin is capable of delivering 500mA including the MCU
current so hopefully if you're not using too much power, you can use that
in the meantime?

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

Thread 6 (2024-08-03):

Explain flashing of FW in README

doniks, 2024-08-03:
Right now, documentation is quite sparse. It took me a while to figure out how to flash (https://github.com/tooyipjee/Spark-Analyzer/issues/2#issuecomment-2263427216) I think this could be better explained. I'd suggest a "Development" section in the README

doniks, 2024-08-03:
basically:

* clone FW
* install PlatformIO
* test/configure serial port
* flash FW
* flash FS
* optionally, measure

doniks, 2024-08-03:
maybe also explain buttons and (uart) pins?

tooyipjee, 2024-08-04:
Could you make a PR for this explaination and feature?

doniks, 2024-08-05:
Yes. Just want to wait for this https://github.com/tooyipjee/Spark-Analyzer/pull/3 to wrap up first

doniks, 2024-08-12:
included in a commit here: https://github.com/tooyipjee/Spark-Analyzer/pull/10/commits

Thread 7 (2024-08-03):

WebApp_PPS does not remember configured values

doniks, 2024-08-03:
repro:
* flash PPS
* configure levels
* -> correct levels set
* unplug/replug
* -> levels are forgotten - NOT OK: levels should be remembered

As far as I can tell, WebApp does this just fine.

doniks, 2024-08-03:
I think it's just due to the WebApp_PPS not using the `Preferences` class as WebApp does.

If that is all it is, then it should be simple to port this from WebApp to WebApp_PPS

doniks, 2024-08-03:
Mhm, so I guess one extra challenge that I didn't see at first is how to store the PPS configuration versus the PD configuration.

I assume (haven't actually verified this) that the preferences are stored somewhere in a separate partition (can't find any partition table) and even when flashing PD vs PPS firmware (or if we would have one that supports both) then the same preferences partition will persist and that would mean the one firmware tries to write an integral value with the key "voltage" while the other firmware tries to write a float, this can't work, and even if it would, it's the whole point of PD vs PPS, that they do not support the same set of output values.

This leads me down a rabbit hole. I'd like to prefix the keys like this: ppsVoltage. In fact I would also prefer to change the variable names accordingly, and in fact I think the web api should be changed as well. One the one hand to make support of both PD and PPS in a single firmware in the future easier, but on the other hand to even avoid odd cases where the firmware has been reflashed, but the spiffs filesystem hasn't and it's serving incompatible values from the wrong web interface ...

So, all of that brings me to the thought that actually I want to change:
* variable names
* and preferences keys
* and web api keys
* and preprocessor macro names for default values

in both projects to keep it consistent. And in fact when I touch that I would like to think about a consistent naming scheme including the units V, A, mA .... aaaand actually I would like to also store the output state and actually the ... whatshallwecallit power supply mode "PS" vs "PPD"

any thoughts on this @tooyipjee ?

tooyipjee, 2024-08-04:
Will try to incorporate some of these suggestions after the summer, thank you.

I the meantime too, happy if you/soemone wants to take point :)

doniks, 2024-08-08:
I'm taking a stab at this. I'll try to post my draft working branch soon, will have to turn into a proper PR after.

But for now the rabbit hole seems to be getting a little deeper :-P

I've added more Serial.print to help me debug. However, I cannot drive PPS from my laptop directly. So, I have to plug the usb c into a power supply brick. Which means I cannot see the debug messages anymore. I was able to connect the second uart from the pin header, but the normal Serial.print() only goes to one .. (the first) initialized uart. So, now I'm looking at using ESP_LOGI, ESP_LOGD, etc instead of Serial... tbc

doniks, 2024-08-08:
very much work in progress branch: https://github.com/doniks/Spark-Analyzer/tree/wip just FYI

doniks, 2024-08-10:
Ugh. No ESP_LOGD and friends don't really work the way I expect either. Apparently only ESP_LOGE is enabled and if I understand it correctly we can't run a esp menuconfig to change that ... I think something like arduino framework versus espressif...

doniks, 2024-08-11:
ok, how about this one: https://github.com/tooyipjee/Spark-Analyzer/pull/10

want to test it a bit more before taking it out of draft status

doniks, 2024-08-17:
updated PR: https://github.com/tooyipjee/Spark-Analyzer/pull/11

doniks, 2024-08-22:
urgh. no GitGuardian didn't like my code, so here we go https://github.com/tooyipjee/Spark-Analyzer/pull/12

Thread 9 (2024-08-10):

start without wifi

doniks, 2024-08-10:
SA blocks during boot when the previously configured wifi is not available. This is rather inconvenient. I'd rather have it:

1. offer the access point mode when we cannot make a wifi connection (either never configured or wifi out of reach)
2. provide the power output if it has been configured previously.

doniks, 2024-08-10:
As far as I can see, right now we're using a blocking call `wifiManager.autoConnect()`

instead we should rather attempt to connect in a non-blocking way similar to this: https://github.com/tzapu/WiFiManager/tree/master/examples/NonBlocking

and make sure that output is only enabled if that has previously been configured (I think that's the case anyway)

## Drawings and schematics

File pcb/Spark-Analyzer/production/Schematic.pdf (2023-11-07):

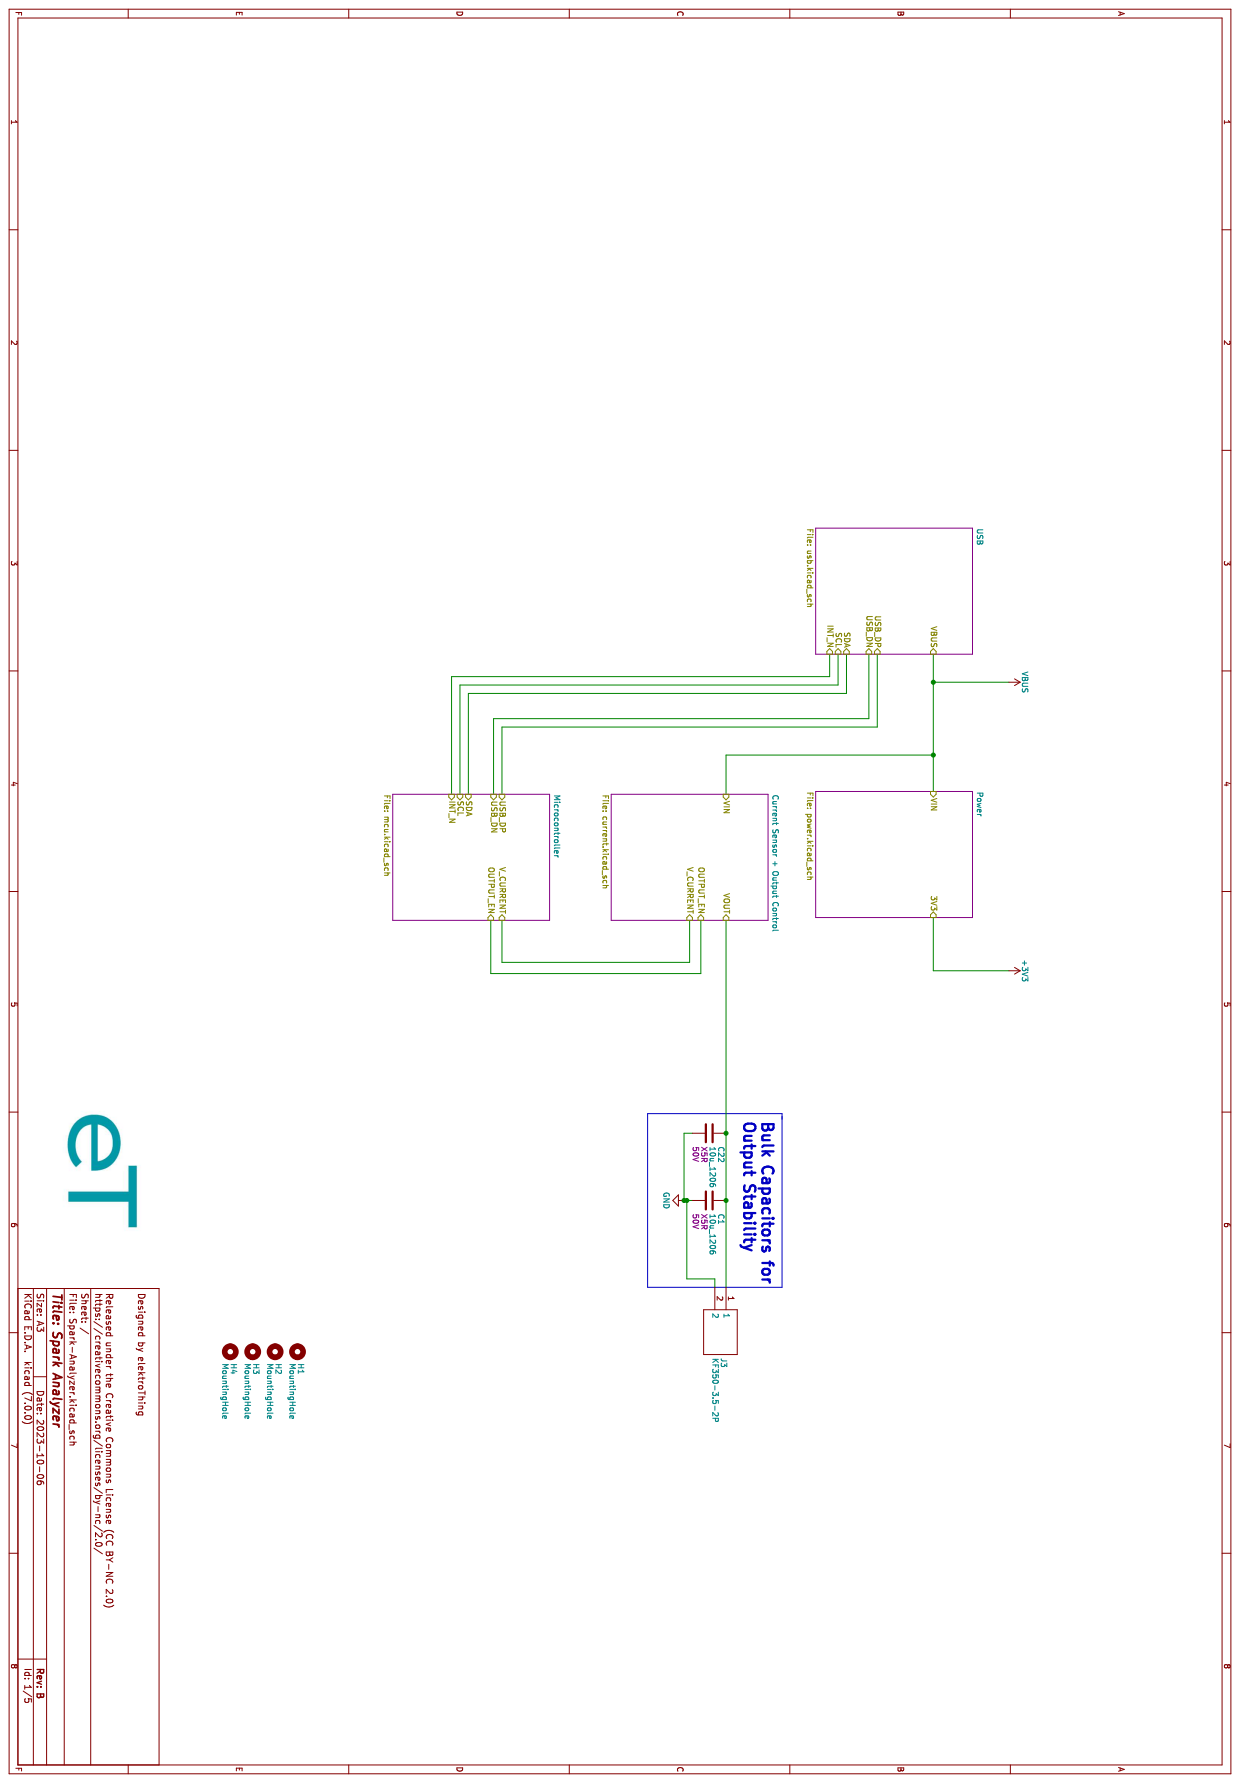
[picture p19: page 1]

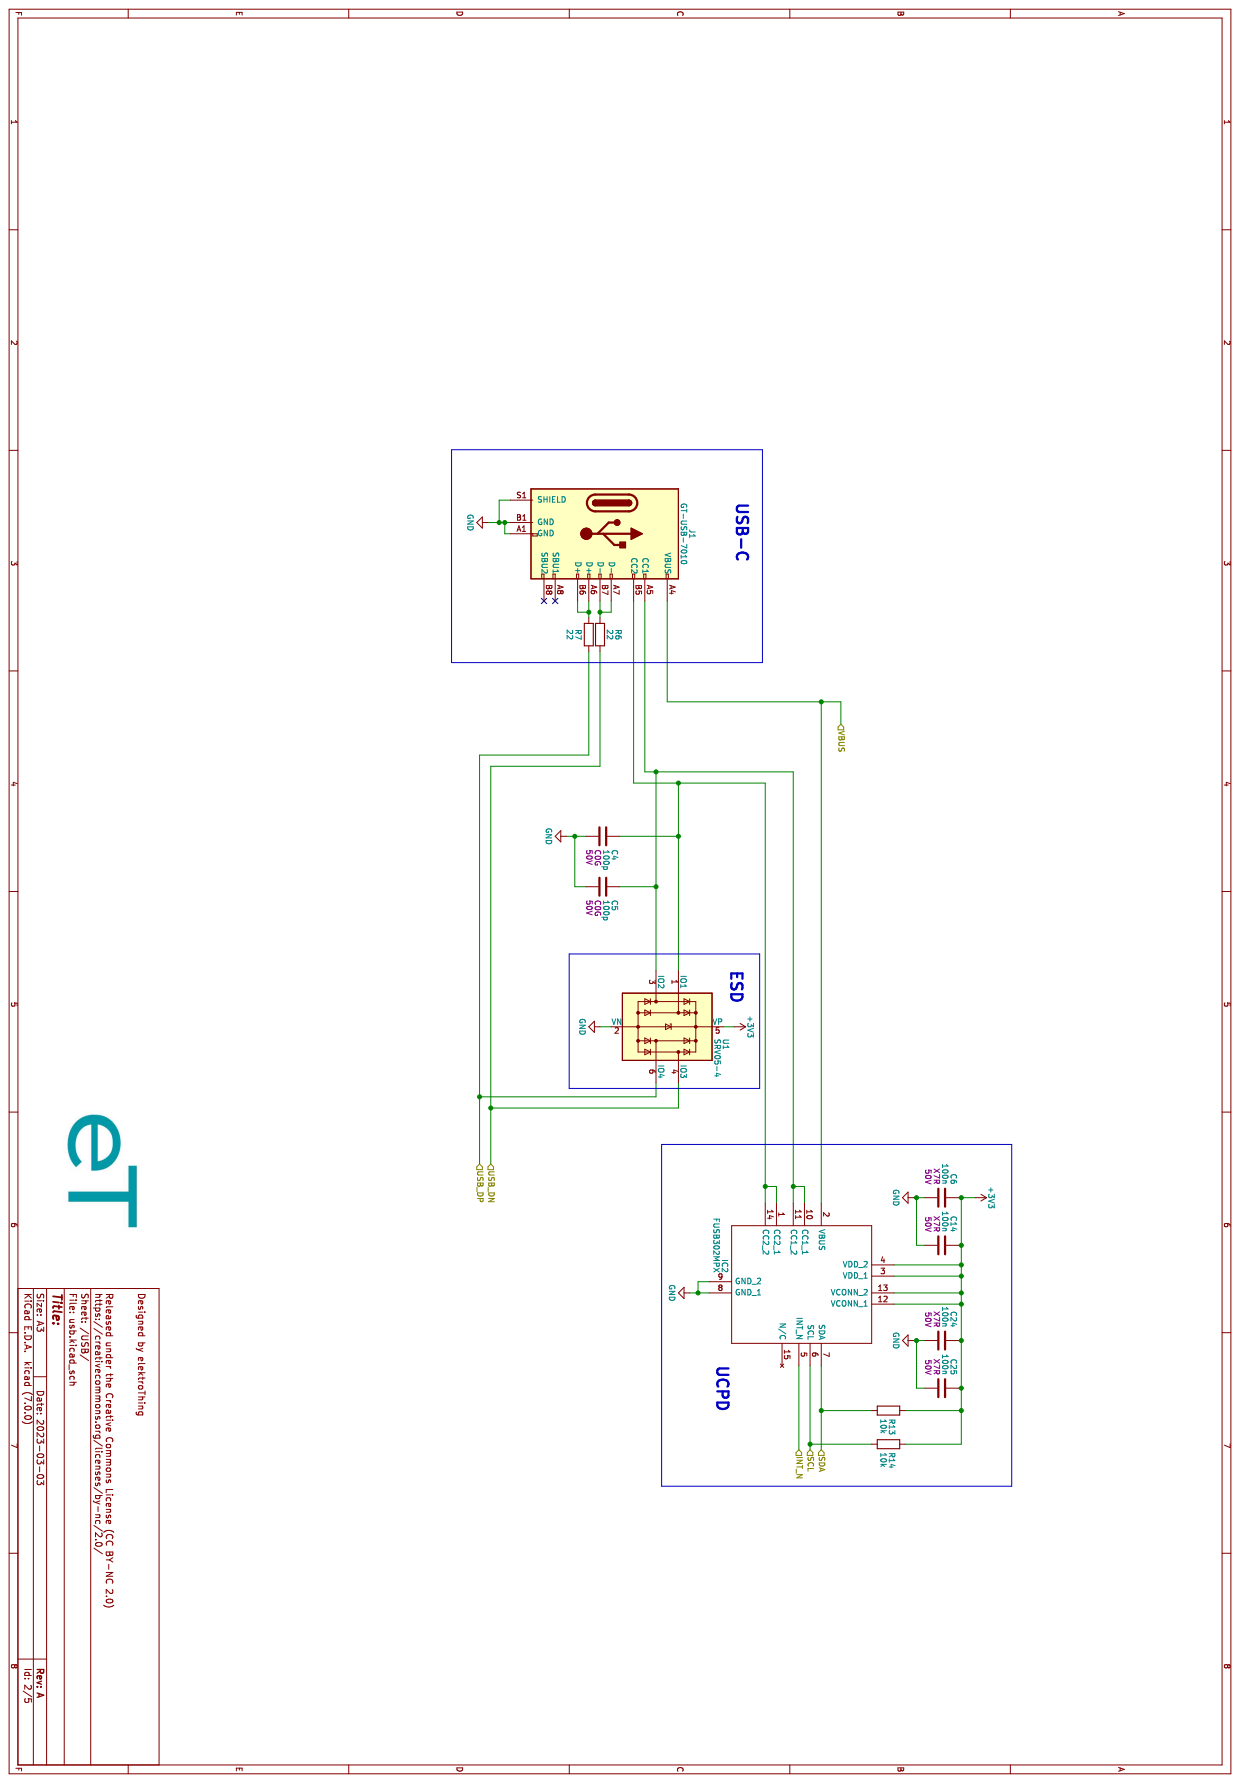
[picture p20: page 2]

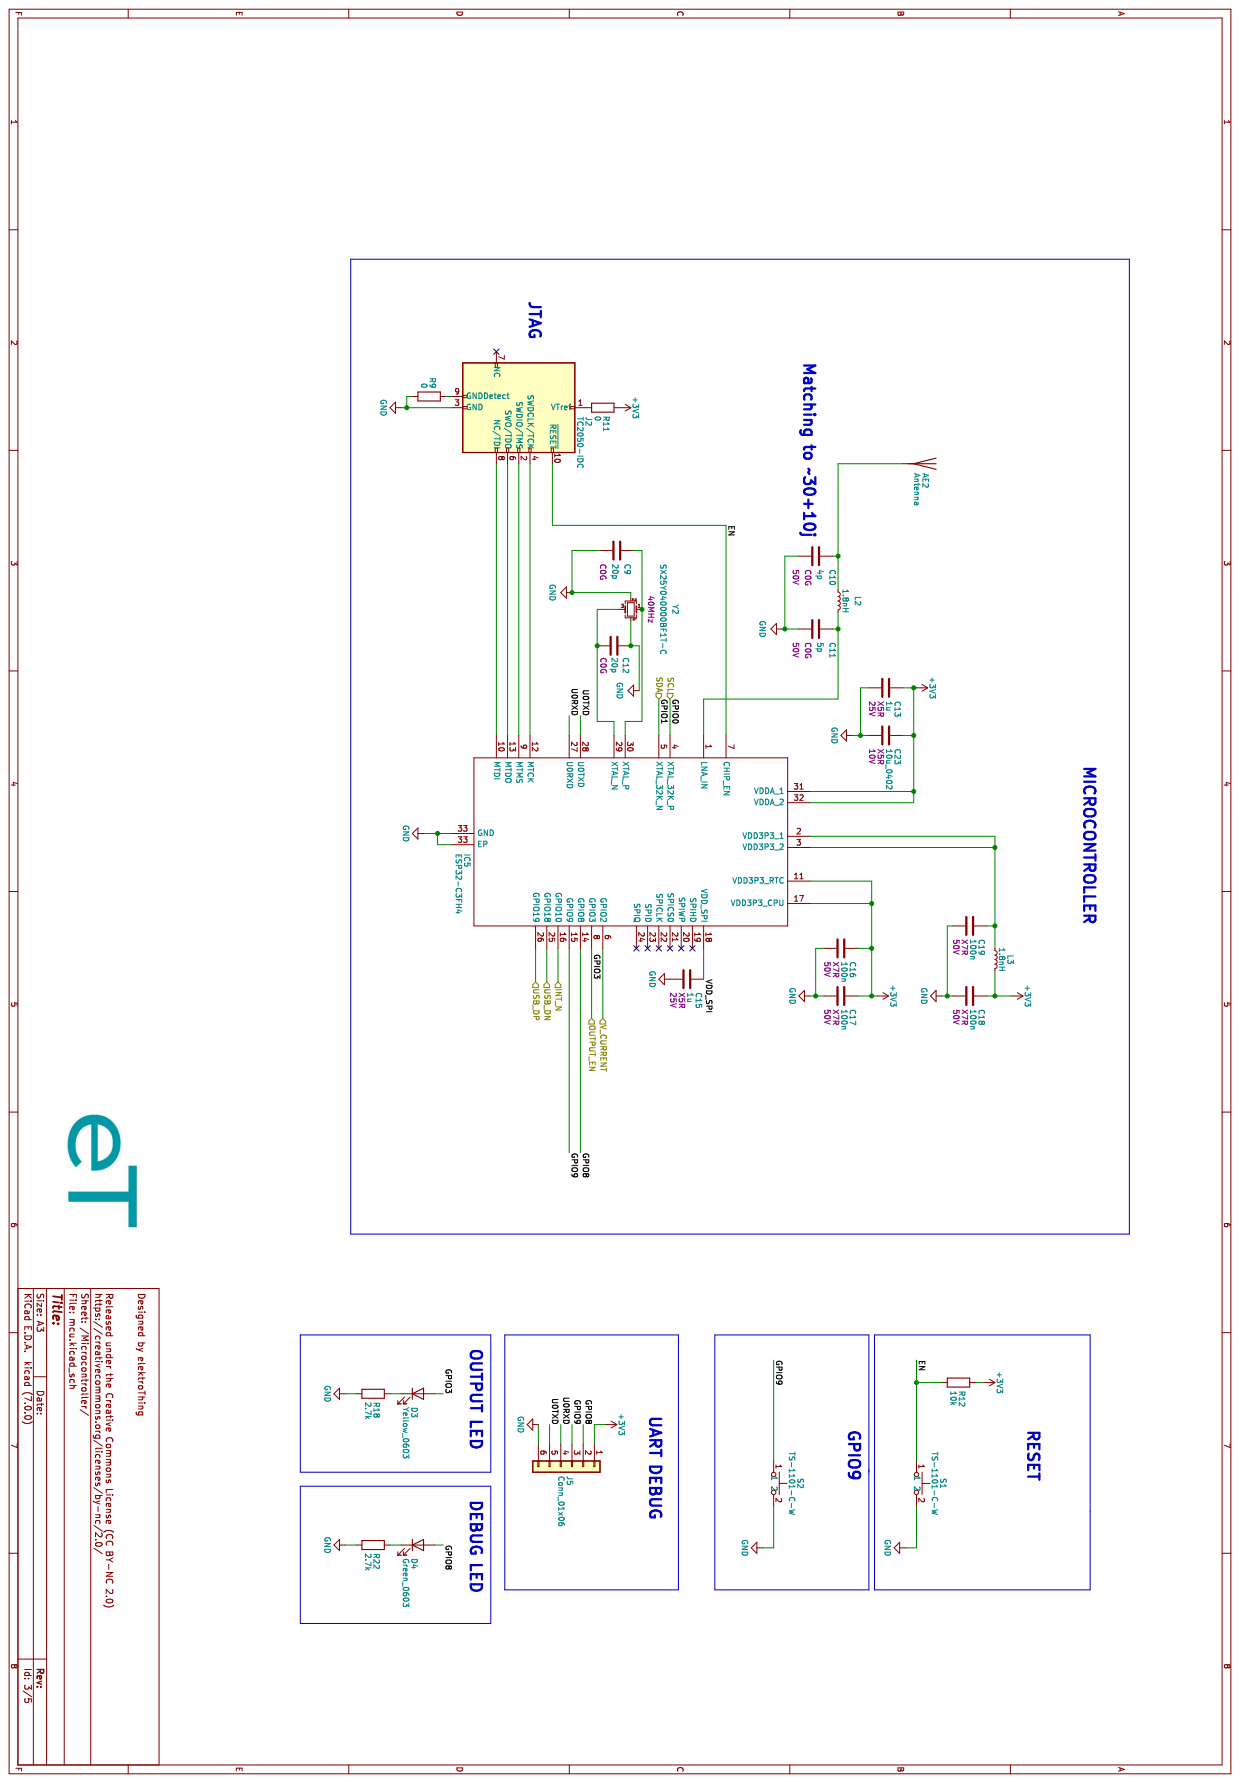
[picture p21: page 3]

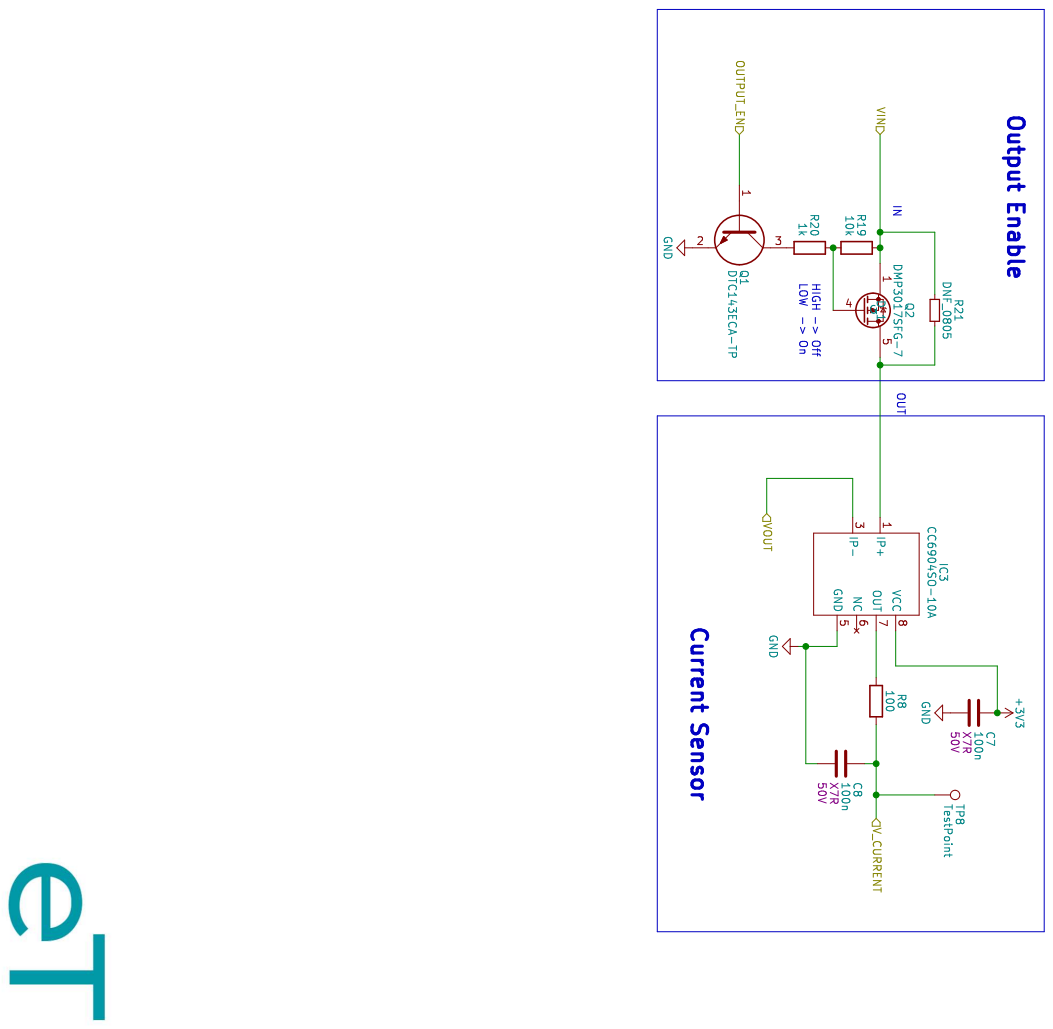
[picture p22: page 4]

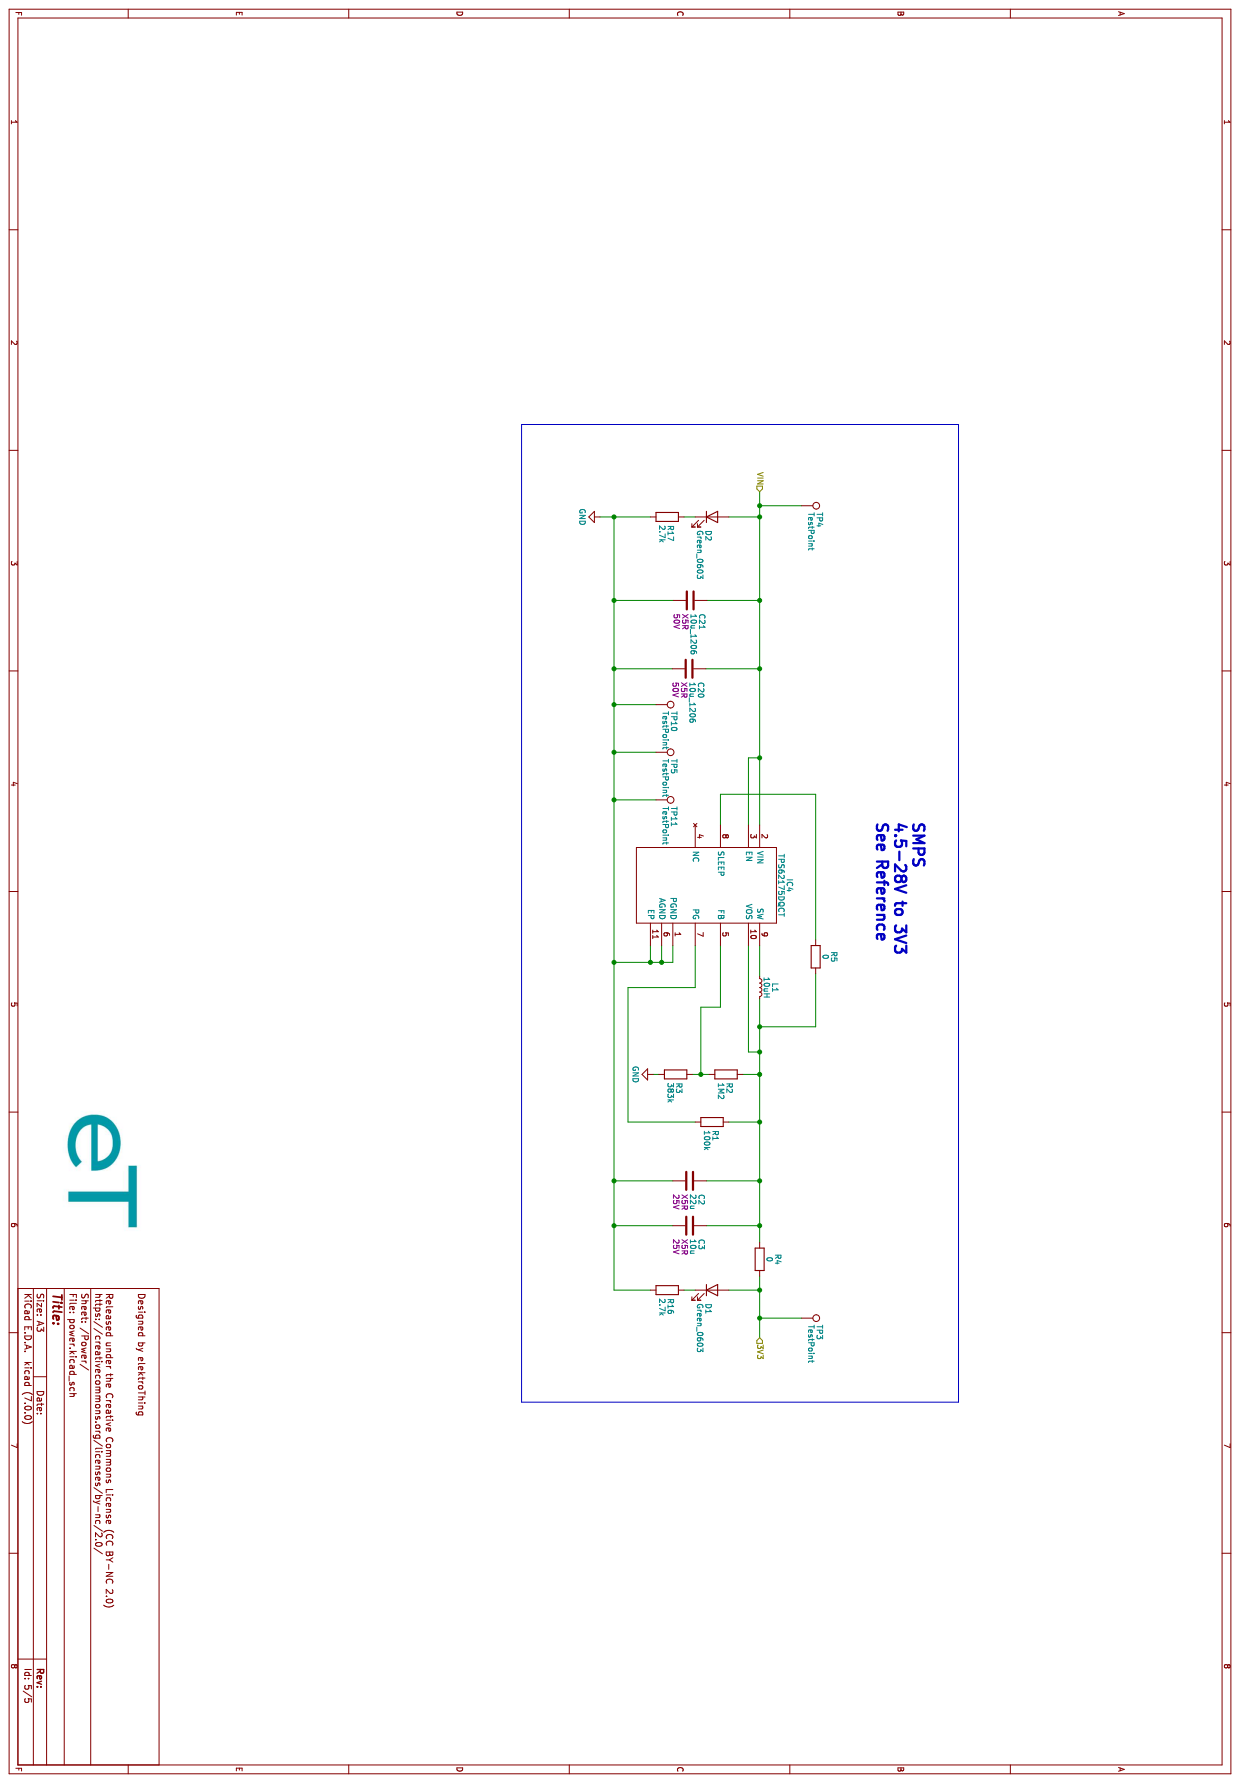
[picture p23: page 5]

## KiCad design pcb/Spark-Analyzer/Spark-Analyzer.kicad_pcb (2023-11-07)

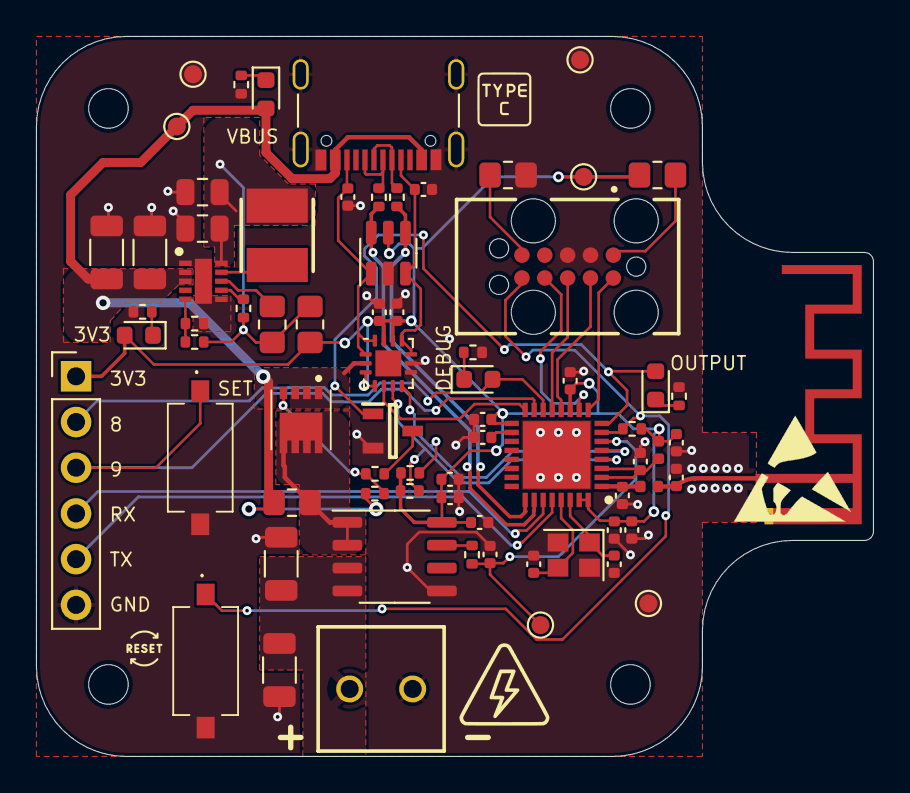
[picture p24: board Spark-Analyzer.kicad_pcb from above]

Board: 4 copper layers, 46.5 x 40.0 mm, 79 parts (1 on the bottom side), 45 nets.

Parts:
 : LOGO; highVoltage
 #2: LOGO; highVoltage
AE2: Antenna; Texas_SWRA117D_2.4GHz_Left
C1, C20, C21, C22: 10u_1206; C_1206_3216Metric
C2: 22u; C_0805_2012Metric
C3: 10u; C_0805_2012Metric
C4, C5: 100p; C_0402_1005Metric
C6, C7, C8, C14, C16, C17, C18, C19, C24, C25: 100n; C_0402_1005Metric
C9, C12: 20p; C_0402_1005Metric
C10: 4p; C_0402_1005Metric
C11: 5p; C_0402_1005Metric
C13, C15: 1u; C_0402_1005Metric
C23: 10u_0402; C_0402_1005Metric
D1, D2, D4: Green_0603; LED_0603_1608Metric
D3: Yellow_0603; LED_0603_1608Metric
H1, H2, H3, H4: MountingHole; MountingHole_2.2mm_M2
IC2: FUSB302MPX; WQFN-14-1EP_2.5x2.5mm_P0.5mm_EP1.45x1.45mm
IC3: CC6904SO-10A; SOP-8_3.9x4.9mm_P1.27mm
IC4: TPS62175DQCT; SON50P200X300X80-11N
IC5: ESP32-C3FH4; QFN50P500X500X90-33N-D
J1: GT-USB-7010; GT-USB-7010A
J2: TC2050-IDC
J3: KF350-3.5-2P; KF350352P
J5: Conn_01x06; PinHeader_1x06_P2.54mm_Vertical
L1: 10uH; INDPM4040X300N
L2, L3: 1.8nH; L_0402_1005Metric
Q1: DTC143ECA-TP; SOT95P237X125-3N
Q2: DMP3017SFG-7; DMP3007SFG7
R1: 100k; R_0402_1005Metric
R2: 1M2; R_0402_1005Metric
R3: 383k; R_0402_1005Metric
R4, R5, R9, R11: 0; R_0805_2012Metric_Pad1.20x1.40mm_HandSolder
R6, R7: 22; R_0402_1005Metric
R8: 100; R_0402_1005Metric
R12, R13, R14, R19: 10k; R_0402_1005Metric
R16, R17, R18, R22: 2.7k; R_0402_1005Metric
R20: 1k; R_0402_1005Metric
R21: DNF_0805; R_0805_2012Metric_Pad1.20x1.40mm_HandSolder
S1, S2: TS-1101-C-W; TS1101CW
TP3, TP4, TP5, TP8, TP10, TP11: TestPoint; TestPoint_Pad_D1.0mm
U1: SRV05-4; SOT-23-6
Y2: SX25Y040000BF1T-C; Crystal_SMD_2520-4Pin_2.5x2.0mm

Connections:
+3V3: C6.2, C7.1, C13.1, C14.2, C16.1, C17.1, C18.1, C23.1, C24.2, C25.2, D1.2 (A), IC2.3 (VDD_1), IC2.4 (VDD_2), IC2.12 (VCONN_1), IC2.13 (VCONN_2), IC3.8 (VCC), IC5.11 (VDD3P3_RTC), IC5.17 (VDD3P3_CPU), IC5.31 (VDDA_1), IC5.32 (VDDA_2), J5.1, L3.2, R4.2, R11.1, R12.1, R13.1, R14.1, TP3.1, U1.5 (VP)
/Current Sensor + Output Control/VOUT: C1.1, C22.1, IC3.3 (IP-), IC3.4 (IP-), J3.1
/Current Sensor + Output Control/V_CURRENT: C8.1, IC5.6 (GPIO2), R8.2, TP8.1
/Microcontroller/EN: IC5.7 (CHIP_EN), J2.10 (~RESET), R12.2, S1.1
/Microcontroller/GPIO0: IC2.6 (SCL), IC5.4 (XTAL_32K_P), R14.2
/Microcontroller/GPIO1: IC2.7 (SDA), IC5.5 (XTAL_32K_N), R13.2
/Microcontroller/GPIO3: D3.2 (A), IC5.8 (GPIO3), Q1.1
/Microcontroller/GPIO8: D4.2 (A), IC5.14 (GPIO8), J5.2
/Microcontroller/GPIO9: IC5.15 (GPIO9), J5.3, S2.1
/Microcontroller/INT_N: IC2.5 (INT_N), IC5.16 (GPIO10)
/Microcontroller/U0RXD: IC5.27 (U0RXD), J5.4
/Microcontroller/U0TXD: IC5.28 (U0TXD), J5.5
/Microcontroller/USB_DN: IC5.25 (GPIO18), R6.2, U1.4 (IO3)
/Microcontroller/USB_DP: IC5.26 (GPIO19), R7.1, U1.6 (IO4)
/Microcontroller/VDD_SPI: C15.1, IC5.18 (VDD_SPI)
GND: C1.2, C2.2, C3.2, C4.2, C5.2, C6.1, C7.2, C8.2, C9.2, C10.2, C11.2, C12.1, C13.2, C14.1, C15.2, C16.2, C17.2, C18.2, C19.2, C20.2, C21.2, C22.2, C23.2, C24.1, C25.1, IC2.8 (GND_1), IC2.9 (GND_2), IC3.5 (GND), IC4.1 (PGND), IC4.6 (AGND), IC4.11 (EP), IC5.33 (GND), J1.A1 (GND), J1.B1 (GND), J1.S1 (SHIELD), J2.3 (GND), J2.5 (GND), J3.2, J5.6, Q1.2, R3.2, R9.2, R16.2, R17.2, R18.2, R22.2, S1.2, S2.2, TP5.1, TP10.1, TP11.1, U1.2 (VN), Y2.2, Y2.4
unnamed: AE2.1 (A), C10.1, L2.1
unnamed: D1.1 (K), R16.1
unnamed: D2.1 (K), R17.1
unnamed: D3.1 (K), R18.1
unnamed: D4.1 (K), R22.1
unnamed: C5.1, IC2.10 (CC1_1), IC2.11 (CC1_2), J1.A5 (CC1), U1.3 (IO2)
unnamed: C4.1, IC2.1 (CC2_1), IC2.14 (CC2_2), J1.B5 (CC2), U1.1 (IO1)
unnamed: IC3.7 (OUT), R8.1
unnamed: IC4.5 (FB), R2.2, R3.1
unnamed: IC4.7 (PG), R1.2
unnamed: IC4.8 (SLEEP), R5.1
unnamed: IC4.9 (SW), L1.1
unnamed: C2.1, C3.1, IC4.10 (VOS), L1.2, R1.1, R2.1, R4.1, R5.2
unnamed: C11.1, IC5.1 (LNA_IN), L2.2
unnamed: IC5.12 (MTCK), J2.4 (SWDCLK/TCK)
unnamed: IC5.10 (MTDI), J2.8 (NC/TDI)
unnamed: IC5.13 (MTDO), J2.6 (SWO/TDO)
unnamed: IC5.9 (MTMS), J2.2 (SWDIO/TMS)
unnamed: C19.1, IC5.2 (VDD3P3_1), IC5.3 (VDD3P3_2), L3.1
unnamed: C12.2, IC5.29 (XTAL_N), Y2.3
unnamed: C9.1, IC5.30 (XTAL_P), Y2.1
unnamed: J1.A6 (D+), J1.B6 (D+), R7.2
unnamed: J1.A7 (D-), J1.B7 (D-), R6.1
unnamed: J2.9 (GNDDetect), R9.1
unnamed: J2.1 (VTref), R11.2
unnamed: Q1.3, R20.2
unnamed: IC3.1 (IP+), IC3.2 (IP+), Q2.5 (D_1), Q2.6, Q2.7, Q2.8, Q2.9, R21.2
unnamed: Q2.4 (G), R19.2, R20.1
VBUS: C20.1, C21.1, D2.2 (A), IC2.2 (VBUS), IC4.2 (VIN), IC4.3 (EN), J1.A4 (VBUS), J1.A9 (VBUS), J1.B4 (VBUS), J1.B9 (VBUS), Q2.1, Q2.2, Q2.3, R19.1, R21.1, TP4.1

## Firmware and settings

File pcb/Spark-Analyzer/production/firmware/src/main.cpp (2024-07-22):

/*
   NOTICE:
   This firmware for the Web App is developed using PlatformIO, an open-source ecosystem
   for IoT development. It leverages the SPIFFS (SPI Flash File System) for handling
   on-device file storage. Ensure that PlatformIO and necessary libraries are installed
   before compiling and uploading this firmware to your device.

   -- Web App Firmware --

   This script is the firmware for the Web App, designed to provide a user interface
   for monitoring and controlling power delivery in smart home applications. Key features
   include real-time current monitoring, voltage adjustment, and power output control.

   Key components and libraries:
     - ESPAsyncWebServer: For handling HTTP requests and serving the web interface.
     - EEPROM: To store and retrieve persistent settings such as the voltage level.
     - WiFiManager: To facilitate easy WiFi connectivity and configuration.
     - SPIFFS: For storing and accessing web interface files.

   Instructions for Loading the Firmware and Web Interface:
   1. Open the project in PlatformIO.
   2. Place the HTML file inside the 'data' directory of your PlatformIO project.
   3. Compile the firmware using PlatformIO. Ensure all library dependencies are resolved.
   4. Upload the firmware to your device using PlatformIO's upload functionality.
   5. Use PlatformIO's "Upload Filesystem Image" command to upload the contents of the 'data' directory
      to your device. This step ensures that the HTML file is stored in the SPIFFS.
   6. When done - connect your Spark Analyzer to your local WiFi using your phone/computer and searching for "Spark Analyzer" access point.
   7. Navigate to 192.168.4.1, and follow the web app to setup the device on your WiFi.
   8. Open serial terminal and the Spark Analyzer will print out it's IP address, navigate to that IP address and you should see the web app.

   Developed by Jason Too
   License: MIT

   MIT License
   Copyright (c) 2023 elektroThing

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
   THE SOFTWARE IS PROVIDED "AS IS", WITHOUT WARRANTY OF ANY KIND, EXPRESS OR IMPLIED,
   INCLUDING BUT NOT LIMITED TO THE WARRANTIES OF MERCHANTABILITY, FITNESS FOR A
   PARTICULAR PURPOSE AND NONINFRINGEMENT. IN NO EVENT SHALL THE AUTHORS OR COPYRIGHT
   HOLDERS BE LIABLE FOR ANY CLAIM, DAMAGES OR OTHER LIABILITY, WHETHER IN AN ACTION
   OF CONTRACT, TORT OR OTHERWISE, ARISING FROM, OUT OF OR IN CONNECTION WITH THE
   SOFTWARE OR THE USE OR OTHER DEALINGS IN THE SOFTWARE.
*/

#include <Arduino.h>
#include <Wire.h>
#include <PD_UFP.h>
#include <WiFi.h>
#include <WiFiManager.h> // Include the WiFiManager library
#include <ESPAsyncWebServer.h>
#include <Preferences.h>
#include "index_html.h"
#include <NimBLEDevice.h>

void initializeSerialAndPins();
void initializeUSB_PD();
void updateStatus();
void processCurrentReading();
int readFilteredADC(int pin);

// User-configurable constants
#define FILTER_LENGTH 10
#define INITIAL_OUTPUT_STATE 0 // 1 for On, 0 for Off
#define VOLTAGE 5

// Filter variables
int adcSamples[FILTER_LENGTH];
int adcIndex = 0;
int adcSum = 0;

unsigned long lastUpdateTime = 0;
const unsigned long updateInterval = 100; // Set sample rate
const int usb_pd_int_pin = 10;
const int output_pin = 3;
const int current_pin = 2;
const int debug_led = 8;
int current = 0;
bool output = INITIAL_OUTPUT_STATE;
int voltage = VOLTAGE;
int adcError = 0;

PD_UFP_c PD_UFP;
Preferences preferences;

void handleVoltageChange(AsyncWebServerRequest *request)
{
  if (request->hasParam("voltage"))
  {
    int newVoltage = request->getParam("voltage")->value().toInt();
    if (newVoltage != voltage)
    {
      // Write new voltage to Preferences
      preferences.putUInt("voltage", newVoltage);
      esp_restart(); // Restart ESP32 to apply new voltage setting
    }
    else
    {
      request->send(200, "text/plain", "Voltage unchanged");
    }
    request->send(200, "text/plain", String(voltage));
  }
  else
  {
    request->send(400, "text/plain", "Voltage parameter missing");
  }
}

void handleOutputControl(AsyncWebServerRequest *request)
{
  if (request->hasParam("output"))
  {
    String outputState = request->getParam("output")->value();
    if (outputState == "1")
    {
      output = true;
      digitalWrite(output_pin, HIGH); // Turn output ON
      request->send(200, "text/plain", "Output Enabled");
    }
    else if (outputState == "0")
    {
      output = false;
      digitalWrite(output_pin, LOW); // Turn output OFF
      request->send(200, "text/plain", "Output Disabled");
    }
    else
    {
      request->send(400, "text/plain", "Invalid output state");
    }
  }
  else
  {
    request->send(400, "text/plain", "Output parameter missing");
  }
}
// Create AsyncWebServer object on port 80
AsyncWebServer server(80);
void setup()
{
  // Initialize Preferences with namespace "storage". False for read/write mode.
  preferences.begin("storage", false);
  // Retrieve stored voltage value or default to VOLTAGE if not set.
  voltage = preferences.getUInt("voltage", VOLTAGE);
  
  pinMode(debug_led, OUTPUT); // Set debug LED as an output before blinking
  // Blink debug LED 5 times
  for (int i = 0; i < 5; i++)
  {
    digitalWrite(debug_led, HIGH);
    delay(250); // Adjust delay time as needed
    digitalWrite(debug_led, LOW);
    if (i < 4) // Avoid delay after the last blink
    {
        delay(500);
    }
  }
  WiFiManager wifiManager;                   // Initialize WiFiManager
  wifiManager.autoConnect("Spark Analyzer"); // Auto-connect to WiFi. Change "ESP32_Device" to your desired AP name

  Serial.begin(115200);
  Serial.println("Connected to WiFi");

  initializeUSB_PD();
  for (int i = 0; i < 30; i++)
  {
    processCurrentReading();
  }
  initializeSerialAndPins();

  Serial.print("To access the web app, open your browser and navigate to -> ");
  Serial.println(WiFi.localIP());

  server.on("/", HTTP_GET, [](AsyncWebServerRequest *request)
            { request->send(200, "text/html", index_html); });
  server.on("/current", HTTP_GET, [](AsyncWebServerRequest *request)
            { request->send(200, "text/plain", String(current)); });
  server.on("/get_voltage", HTTP_GET, [](AsyncWebServerRequest *request)
            { request->send(200, "text/plain", String(voltage)); });
  server.on("/set_voltage", HTTP_GET, handleVoltageChange);

  server.on("/set_output", HTTP_GET, handleOutputControl);
  server.begin();

  // Debug pin lights up when ready.
  pinMode(debug_led, OUTPUT);
  digitalWrite(debug_led, HIGH);

  String ipAddress = WiFi.localIP().toString();

  // Prepare the device name with the IP address embedded
  String deviceName = "SparkAnalyzer " + ipAddress;

  // Initialize BLE with the new device name
  BLEDevice::init(deviceName.c_str());

  // Get a reference to the existing advertising
  NimBLEAdvertising *pAdvertising = BLEDevice::getAdvertising();

  // Since we're now using the device name to convey the IP address,
  // we don't need to set custom advertising data for the IP.
  // Just configure the advertisement to include the service UUID you want to advertise.
  // Note: BLEUUID needs to be adjusted as per your application's requirement.
  pAdvertising->addServiceUUID(BLEUUID("1234"));

  // Start advertising
  BLEDevice::startAdvertising();
}

void loop()
{
  updateStatus();
  processCurrentReading();
}

// Initialize Serial and Pin Modes
void initializeSerialAndPins()
{
  Serial.begin(115200);
  Serial.println("Initializing...");

  pinMode(usb_pd_int_pin, INPUT);
  pinMode(output_pin, OUTPUT);
  digitalWrite(output_pin, LOW);

  pinMode(current_pin, INPUT);
}

// Initialize USB Power Delivery
void initializeUSB_PD()
{
  Wire.begin(1, 0);
  Wire.setClock(400000);
  if (voltage == 5)
  {
    PD_UFP.init(usb_pd_int_pin, PD_POWER_OPTION_MAX_5V);
  }
  else if (voltage == 9)
  {
    PD_UFP.init(usb_pd_int_pin, PD_POWER_OPTION_MAX_9V);
  }
  else if (voltage == 12)
  {
    PD_UFP.init(usb_pd_int_pin, PD_POWER_OPTION_MAX_12V);
  }
  else if (voltage == 15)
  {
    PD_UFP.init(usb_pd_int_pin, PD_POWER_OPTION_MAX_15V);
  }
  else if (voltage == 20)
  {
    PD_UFP.init(usb_pd_int_pin, PD_POWER_OPTION_MAX_20V);
  }
}

// Update status at intervals
void updateStatus()
{
  if (millis() - lastUpdateTime >= updateInterval)
  {
    lastUpdateTime = millis();
    // Add any periodic update logic here
  }
  PD_UFP.run();
}

// Process current reading and adjust LED status
void processCurrentReading()
{
  if (output)
  {
    digitalWrite(output_pin, HIGH);
  }
  else
  {
    adcError = readFilteredADC(current_pin);
    digitalWrite(output_pin, LOW);
  }
  current = 5.6865 * (readFilteredADC(current_pin) - adcError);
}

// Reads ADC value with a moving average filter
int readFilteredADC(int pin)
{
  int newSample = analogRead(pin);
  adcSum -= adcSamples[adcIndex];
  adcSamples[adcIndex] = newSample;
  adcSum += newSample;
  adcIndex = (adcIndex + 1) % FILTER_LENGTH;
  return adcSum / FILTER_LENGTH;
}

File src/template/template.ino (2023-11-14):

#include <Arduino.h>
#include <Wire.h>
#include "tcpm_driver.h"
#include "usb_pd.h"

// User-configurable constants
#define FILTER_LENGTH 10
#define INITIAL_OUTPUT_STATE 1 // 1 for On, 0 for Off
#define CURRENT_LIMIT 0        // Set to desired limit, 0 for no limit
#define VOLTAGE 5

// Filter variables
int adcSamples[FILTER_LENGTH];
int adcIndex = 0;
int adcSum = 0;

unsigned long lastUpdateTime = 0;
const unsigned long updateInterval = 500; // 500ms
const int usb_pd_int_pin = 10;
const int debug_led_pin  = 3;
const int current_pin = 2;
int current = 0;
bool output = INITIAL_OUTPUT_STATE;
int voltage = VOLTAGE;
int adcError = 0;

// USB-C Specific - TCPM start
const struct tcpc_config_t tcpc_config[CONFIG_USB_PD_PORT_COUNT] = {
  {0, fusb302_I2C_SLAVE_ADDR, &fusb302_tcpm_drv},
};

void setup() {
  initializeFilter();
  initializeSerialAndPins();
  initializeUSB_PD();
}

void loop() {
  updateStatus();
  processCurrentReading();
  checkCurrentLimit();
}

// Initialize the ADC filter
void initializeFilter() {
  for (int i = 0; i < FILTER_LENGTH; i++) {
    adcSamples[i] = analogRead(current_pin);
    adcSum += adcSamples[i];
    delay(1); // Short delay for diverse samples
  }
}

// Initialize Serial and Pin Modes
void initializeSerialAndPins() {
  Serial.begin(115200);
  Serial.println("Initializing...");

  pinMode(usb_pd_int_pin, INPUT);
  pinMode(debug_led_pin, OUTPUT);
  digitalWrite(debug_led_pin, HIGH);
  pinMode(current_pin, INPUT);
}

// Initialize USB Power Delivery
void initializeUSB_PD() {
  Wire.begin(1, 0);
  Wire.setClock(400000);
  delay(500);
  tcpm_init(0);
  delay(50);
  pd_init(0);
  delay(50);
  pd_set_max_voltage(voltage*1000); // Set default 5V
}

// Update status at intervals
void updateStatus() {
  if (millis() - lastUpdateTime >= updateInterval) {
    lastUpdateTime = millis();
    // Add any periodic update logic here
  }
  pd_run_state_machine(0);
}

// Process current reading and adjust LED status
void processCurrentReading() {
  if(output) {
    digitalWrite(debug_led_pin, HIGH);
  } else {
    adcError = readFilteredADC(current_pin);
    digitalWrite(debug_led_pin, LOW);
  }
  current = 5.6865 * (readFilteredADC(current_pin) - adcError);
}

// Check if current exceeds limit
void checkCurrentLimit() {
  if(current > CURRENT_LIMIT && CURRENT_LIMIT != 0) {
    output = 0;
  }
}

// Reads ADC value with a moving average filter
int readFilteredADC(int pin) {
    int newSample = analogRead(pin);
    adcSum -= adcSamples[adcIndex];
    adcSamples[adcIndex] = newSample;
    adcSum += newSample;
    adcIndex = (adcIndex + 1) % FILTER_LENGTH;
    return adcSum / FILTER_LENGTH;
}

// Additional functions for USB PD or other functionalities can be added here

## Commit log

2023-03-05 done SCH review and layout placement
    [PowerPod.kicad_pcb, PowerPod.kicad_sch, WBBOMDesign22.csv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]
2023-03-18 finished layout
    [PowerPod.kicad_pcb, PowerPod.kicad_sch, current.kicad_sch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]
2023-03-18 changed gpio pins
    [PowerPod.kicad_pcb, mcu.kicad_sch, usb.kicad_sch]
2023-04-18 created production files
    [PowerPod.kicad_pcb, PowerPod.kicad_sch, bom.csv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]
2023-05-20 Updated code for current measurement
    [mcu.kicad_sch]
2023-05-21 Updated ble code with current measure
2023-05-21 Commented out printlns
2023-10-06 Updated name to Spark Analyzer
    [Spark-Analyzer.kicad_pcb, Spark-Analyzer.kicad_sch, WBBOMDesign22.csv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]
2023-11-03 First app release and updated PCBA
    [Spark-Analyzer.kicad_pcb, Spark-Analyzer.kicad_sch, bom.csv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]
2023-11-07 Added silkscreen symbols and texts
    [Spark-Analyzer.kicad_pcb, designators.csv, mcu.kicad_sch]
2023-11-14 Added remoteXY code for iOS and created a template project
    [Board Outline with Margins.dxf, Board Outline.dxf, PCB_Outline.dxf]
2023-11-26 Improved stability of app
    [flutter_controller.ino]
2024-03-31 updated gitignore
    [Enclosure v3.stl, Lid v1.stl]
